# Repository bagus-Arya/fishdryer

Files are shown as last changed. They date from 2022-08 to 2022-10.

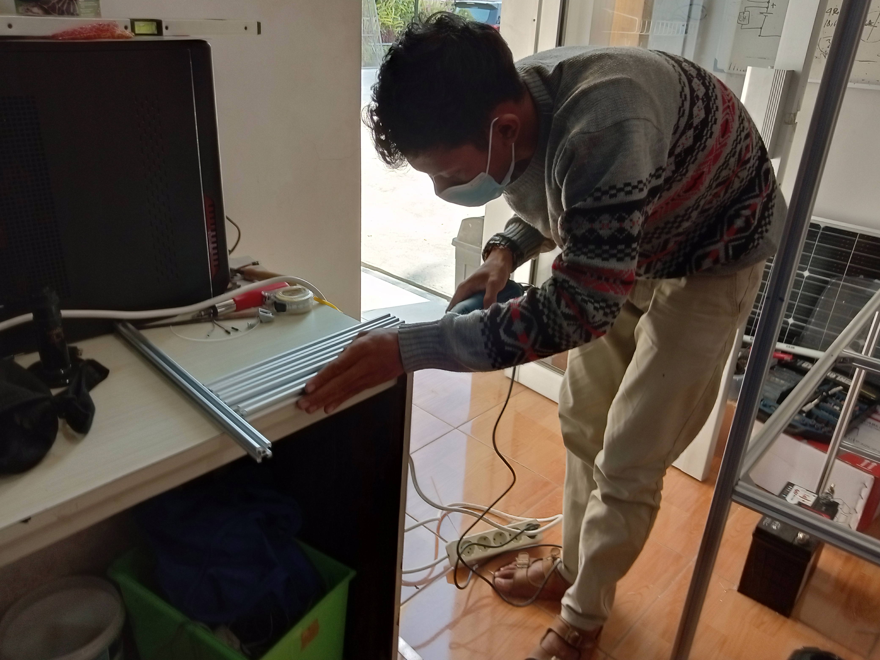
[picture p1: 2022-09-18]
Laporan kemajuan fisheris/foto/IMG_20220820_165149_140.jpg

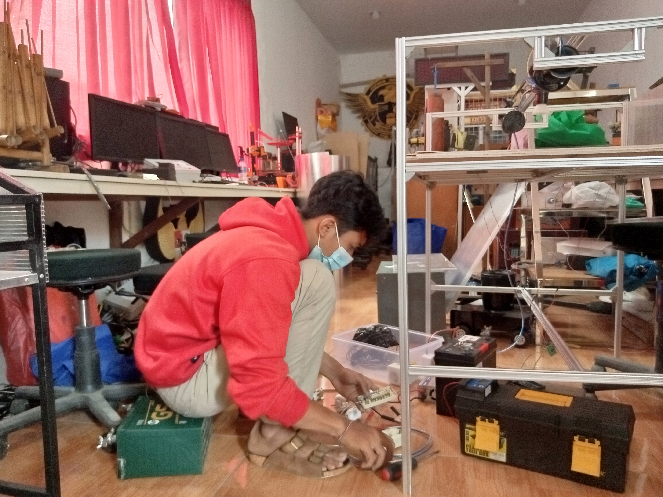
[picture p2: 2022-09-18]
Laporan kemajuan fisheris/foto/IMG_20220829_140725_547.jpg

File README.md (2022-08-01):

<p align="center"></p>

<p align="center">




</p>

## About Laravel

Laravel is a web application framework with expressive, elegant syntax. We believe development must be an enjoyable and creative experience to be truly fulfilling. Laravel takes the pain out of development by easing common tasks used in many web projects, such as:

- [Simple, fast routing engine](https://laravel.com/docs/routing).
- [Powerful dependency injection container](https://laravel.com/docs/container).
- Multiple back-ends for [session](https://laravel.com/docs/session) and [cache](https://laravel.com/docs/cache) storage.
- Expressive, intuitive [database ORM](https://laravel.com/docs/eloquent).
- Database agnostic [schema migrations](https://laravel.com/docs/migrations).
- [Robust background job processing](https://laravel.com/docs/queues).
- [Real-time event broadcasting](https://laravel.com/docs/broadcasting).

Laravel is accessible, powerful, and provides tools required for large, robust applications.

## Learning Laravel

Laravel has the most extensive and thorough [documentation](https://laravel.com/docs) and video tutorial library of all modern web application frameworks, making it a breeze to get started with the framework.

If you don't feel like reading, [Laracasts](https://laracasts.com) can help. Laracasts contains over 2000 video tutorials on a range of topics including Laravel, modern PHP, unit testing, and JavaScript. Boost your skills by digging into our comprehensive video library.

## Laravel Sponsors

We would like to extend our thanks to the following sponsors for funding Laravel development. If you are interested in becoming a sponsor, please visit the Laravel [Patreon page](https://patreon.com/taylorotwell).

### Premium Partners

- **[Vehikl](https://vehikl.com/)**
- **[Tighten Co.](https://tighten.co)**
- **[Kirschbaum Development Group](https://kirschbaumdevelopment.com)**
- **[64 Robots](https://64robots.com)**
- **[Cubet Techno Labs](https://cubettech.com)**
- **[Cyber-Duck](https://cyber-duck.co.uk)**
- **[Many](https://www.many.co.uk)**
- **[Webdock, Fast VPS Hosting](https://www.webdock.io/en)**
- **[DevSquad](https://devsquad.com)**
- **[Curotec](https://www.curotec.com/services/technologies/laravel/)**
- **[OP.GG](https://op.gg)**
- **[WebReinvent](https://webreinvent.com/?utm_source=laravel&utm_medium=github&utm_campaign=patreon-sponsors)**
- **[Lendio](https://lendio.com)**

## Contributing

Thank you for considering contributing to the Laravel framework! The contribution guide can be found in the [Laravel documentation](https://laravel.com/docs/contributions).

## Code of Conduct

In order to ensure that the Laravel community is welcoming to all, please review and abide by the [Code of Conduct](https://laravel.com/docs/contributions#code-of-conduct).

## Security Vulnerabilities

If you discover a security vulnerability within Laravel, please send an e-mail to Taylor Otwell via [taylor@laravel.com](mailto:taylor@laravel.com). All security vulnerabilities will be promptly addressed.

## License

The Laravel framework is open-sourced software licensed under the [MIT license](https://opensource.org/licenses/MIT).
# fishdryer

# fishdryer

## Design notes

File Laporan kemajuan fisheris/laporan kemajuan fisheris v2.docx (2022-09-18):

Pengisian poin C sampai dengan poin H mengikuti template berikut dan tidak dibatasi jumlah kata atau halaman namun disarankan seringkas mungkin. Dilarang menghapus/memodifikasi template ataupun menghapus penjelasan di setiap poin.

C. HASIL PELAKSANAAN PENELITIAN: Tuliskan secara ringkas hasil pelaksanaan penelitian yang telah dicapai sesuai tahun pelaksanaan penelitian. Penyajian meliputi data, hasil analisis, dan capaian luaran (wajib dan atau tambahan). Seluruh hasil atau capaian yang dilaporkan harus berkaitan dengan tahapan pelaksanaan penelitian sebagaimana direncanakan pada proposal. Penyajian data dapat berupa gambar, tabel, grafik, dan sejenisnya, serta analisis didukung dengan sumber pustaka primer yang relevan dan terkini.

I. Perancangan Sistem

Dalam membangun sistem pengeringan ikan ini,tahap pertama yang dilakukan adalah proses perancangan.Pada tahap ini peneliti akan menganalisa kebutuhan sistem dan mendesign sistem baik dari segi sofware ataupun hardwarenya.

  A. Analisi Kebutuhan Sistem

Analisis kebutuhan sistem dilakukan untuk mengindentifikasi fungsi utama yang tersedia pada sistem yang dibangun.Berikut merupakan analisi kebutuhan sistem pada penelitian ini.

1) Sistem dapat melindungi kondisi fisik ikan dari serangga,belatung ataupun cuaca yang tidak mendukung.
2) Sistem dapat memberikan penghangat saat kondisi cuaca kurang baik atau pada malam hari.
3) Sistem mampu memantau suhu ,berat dan intensitas cahaya di sekitarnya.
4) Sistem mampu mengirimkan data-data suhu, berat dan intentsitas cahaya ke website dan menampilkan data tersebut dalam bentuk graph untuk memudahkan nelayan memantau kondisi ikan dan lingkuan sekitar area pengeringan.
5) Sistem akan menggunakan solar panel dan aki sebagai power supply sistem.
  B. Blok Diagram

Gambar 3. Blok Diagram Sistem

Diagram blok dari sistem pegeringan ikan dapat dilihat pada Gambar 3. blok diagram sistem.Arduino mega dan sim module 900 mendapatkan daya dari batrai aki 12v/5Ah yang telah di turunkan teganganya dari 12v dc menjadi 5v dc menggunakan buck converter. Pengecasan aki dilakukan secara otomatis menggunakan charge controller yang telah terhubung dengan panel surya.Batrai aki 12v langsung terhubug ke relay untuk memberikan tegangan ke inverter, sehingga lampu dan heater bertengangan220v dapat menyala. Relay dikontrol oleh microcontroller yang mendapatkan inputan nilai lux meter module. Terdapat 3 inputan yaitu sensor suhu menggunakan ds18b20, sensor berat loadcell 50kg, dan Lux meter module menggunakan bh1750. Arduino mega mengolah data inputan kemudian sim module 900 mengirimkan data tersebut ke website, dan pengguna dapat melihat informasi berat,suhu,dan intensitas cahaya dari website dengan tampilan graph data. Data suhu dan berat juga dapat dilihat langsung melalui LCD Module.

  C. Flow Chart

Gambar 4. Flowchart Sistem

Flow kerja sistem dapat dilihat pada Gambar 4. Flowchart Sistem.Pertama-tama Arduino akan melakukan inisialisasi dan penyetingan awal sensor-sensor dan module sim guna mengecek kesiapan module-module tersebut.Setelah semua komponen sudah berjalan dengan baik, Arduino mega akan mengambil data suhu,berat,intensitas cahay serta sinyal gsm dari module-module yang sudah terinisialisasi sebelumnya.Lalu arduino mega akan menampilkan data-data tersebut ke LCD untuk memperlihatkan status kondisi lingkungan sekitar sistem.Lalu sistem akan mengecek apakah data intesitas cahaya yang di dapatkan kurang dari 150 lx.Jika iya maka arduino akan menghidupkan lampu dan heater dari sistem pengeringan ikan.Jika tidak maka lampu dan heater akan mati.Setelah itu arduino mega akan mengirimkan data-data yang didapatkan dari proses sebelumnya ke website menggunakan sim module setiap 30 detik.Jika waktu pengiriman data sudah sama atau lebih dari 30 detik maka data akan dikirim ke website. Jika tidak maka arduino mega akan kembali ke proses pengambilan data-data sensor dan sinyal gsm.

  D. Skematik Alat

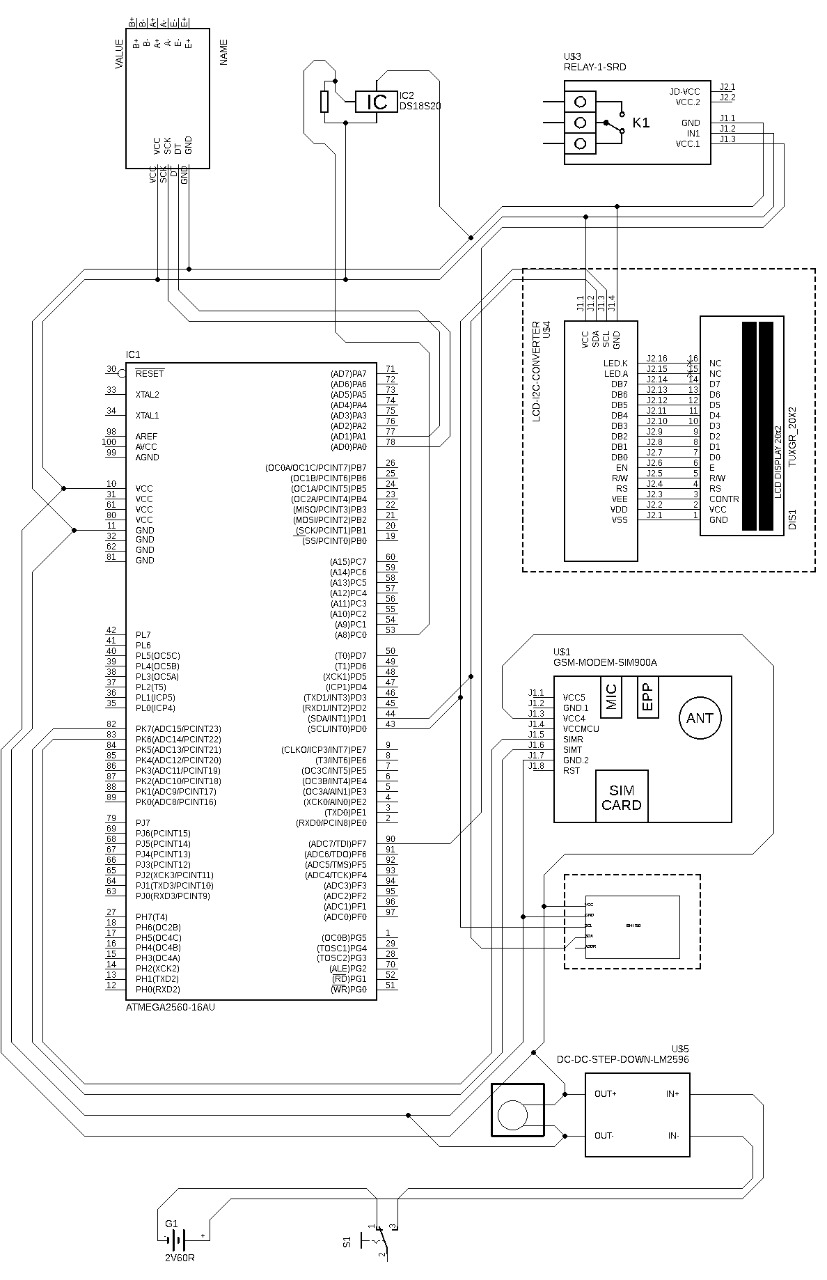
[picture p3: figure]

Gambar 5. Skematik Sistem

Skematik rangkaian dari alat pengeringan ikan ditunjukkan pada Gambar 5. Terdapat 1 buck converter yang terhubung dengan microcontroller Atmega2560 dan modul GSM SIM 900.SIM 900 akan terhubung ke pin rx dan tx pada microcontroller untuk berkomonukasi secara serial.Sedangkan LCD dan sensor lux BH1750 akan terkoneksi ke pin sda dan scl microcontroller untuk berkomunikasi dengan protokol I2C.Sensor DS18B20 akan terkonesi ke pin PC0 yang dimana pin tersebut memiliki kemampuan untuk membaca analog input.Relay akan terkonesi ke pin PF7 yang akan memberikan sinyal relay untuk menghidup matikan lampu.Dan yang terakhir adalah HX1711 yang dimana pin DT dan SCK akan terhubung ke pin PA1 dan PA0.

  E. Peracangan Design PCB

Berdasarkan dari skematik yang telah dirancang maka dibuatlah Peracngan PCB sebagai berikut Pada Gambar dibawah ini

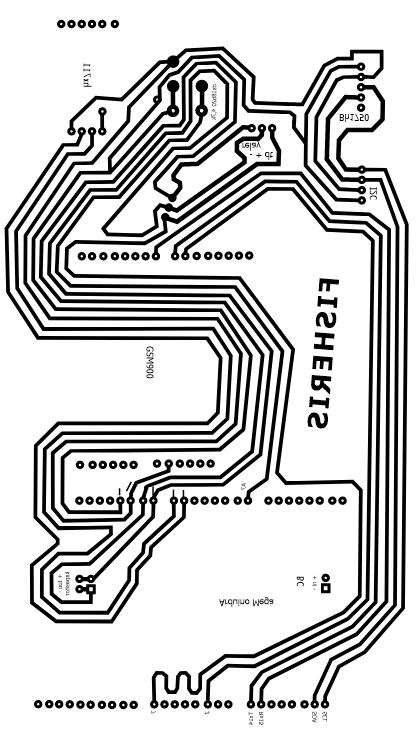
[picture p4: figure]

Gambar 6. Design PCB

  F. Perancangan Box Kontroller Solar Panel,Tempat Pengeringan Ikan dan Penyangga Solar Panel

Pada sisi hardware terdapat 2 bagian utama dari sistem yaitu perancangan box kontroller dan tempat pengeringan ikan.

1) Box Kontroller

Box kontroller adalah tempat menaruh komponen-komponen elektrikal yang di butuhkan untuk menjalankan sistem.Box ini akan melindungi komponen-komponen electrikal dari pengaruh korosif kondisi pantai yang membuat bahan metal berkarat.Box ini berukuran x x x . Pada Gambar 7. Merupakan gambar box kontroller dari sistem yang di buat.

Gambar 7. Box Kontroller

2) Tempat Pengeringan Ikan

Tempat pengeringan ikan merupakan tempat diamana proses pengeringan ikan akan dilakukan.Tempat pengeringan ikan ini dibuat menggunakan aluminium profile dengan dimensi x x x.Di tempat pengeringan ikan ini akan ditaruh 1 lampu dan 2 buah heater dan sistem timbangan untuk mengukur berat ikan.

Gambar 8. Tempat Pengeringan Ikan

  G. Peracangan Tampilan Website
    1) Tampilan Halaman Login

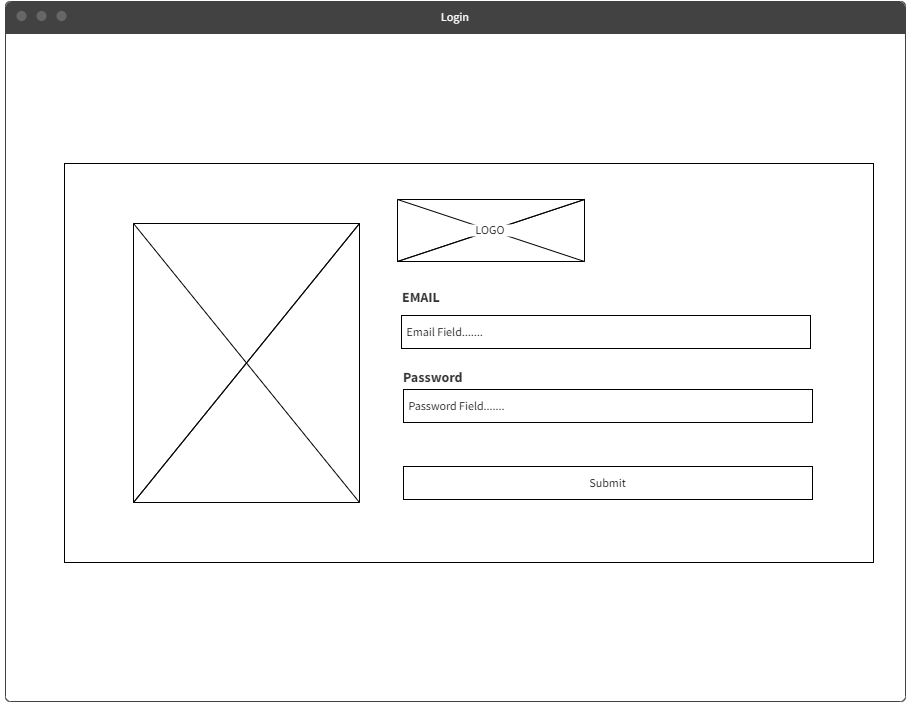
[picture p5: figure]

Gambar 8. Tampilan Halaman Login

Halaman login merupakan halaman yang pertama kali muncul saat mengakses website.Untuk dapat melihat data-data yang telah dikirimkan oleh sistem pengering ikan.User harus terlebih dahulu melakukan login ke website dengan menggunakan email dan password yang sudah terdaftar.

    2) Tampilan Halaman Dashboard

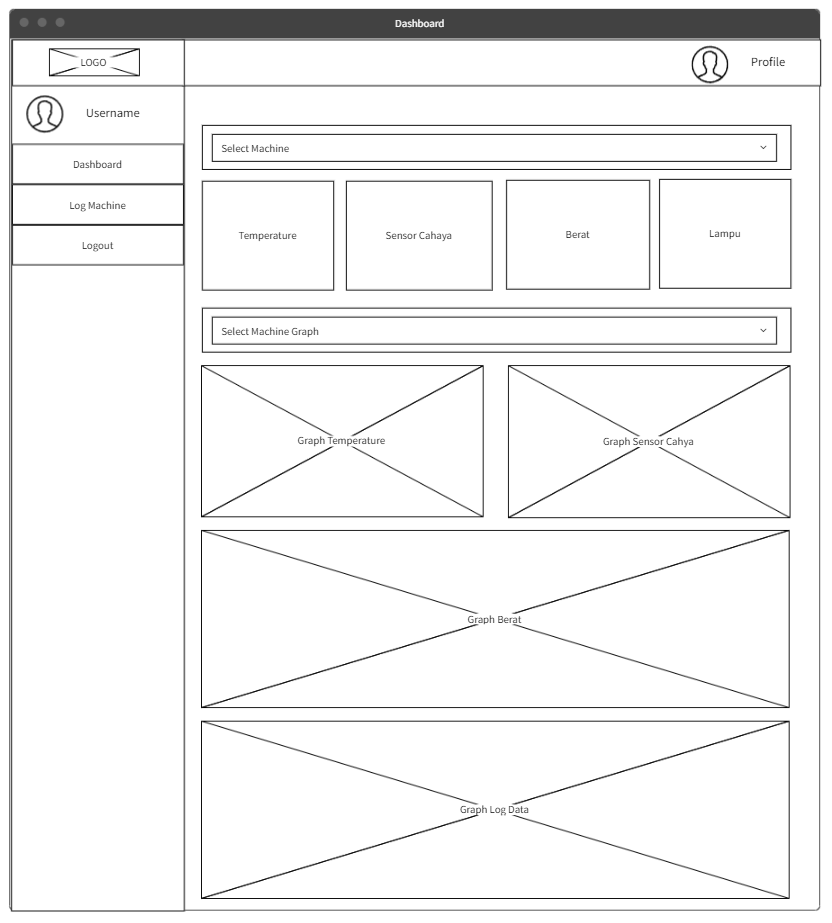
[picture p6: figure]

Gambar 9. Tampilan Halaman Dashboard

Jika login berhasil maka webrowser akan mengarahkan user ke halaman dashboard.Pada halaman ini akan terdapat data yang telah di filter dan diolah dalam bentuk graph chart dan line char.Selain itu terdapat juga tampilan data terakhir yang dikirimkan oleh sistem pengeringan ikan.

    3) Tampilan Halaman Log Machine

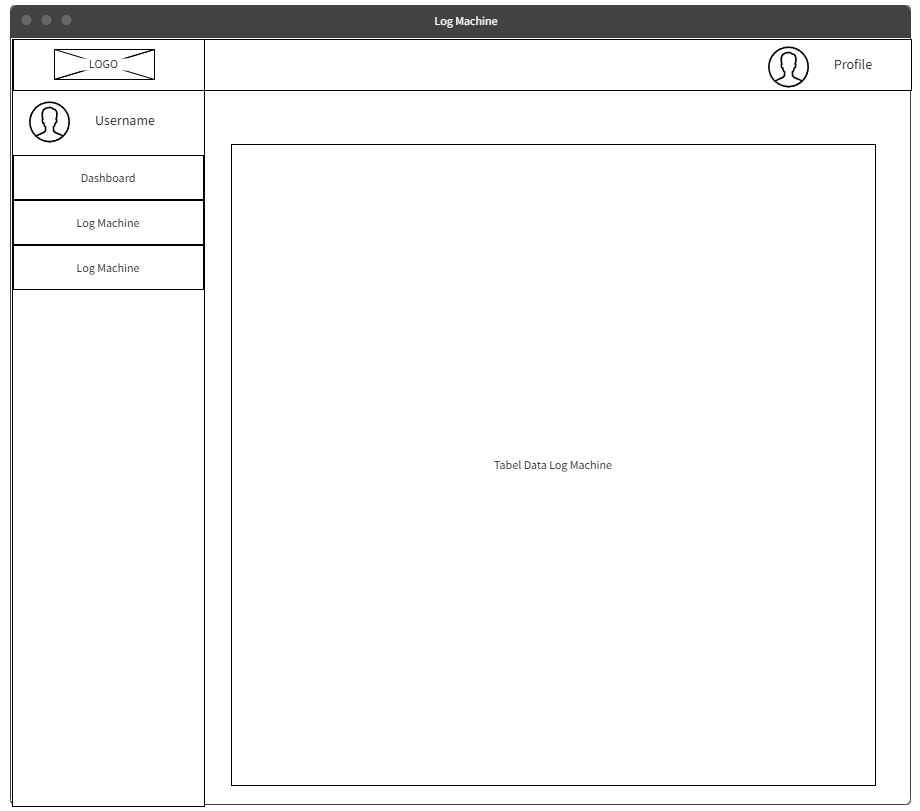
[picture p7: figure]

Gambar 10. Tampilan Halaman Dashboard Line Chart

Tampilan Halaman Log Machine merupakan tampilan history data-data yang dikirimkan oleh sistem pengeringan ikan dalam bentuk tabel.

II. Implementasi Sistem

D. STATUS LUARAN: Tuliskan jenis, identitas dan status ketercapaian setiap luaran wajib dan luaran tambahan (jika ada) yang dijanjikan. Jenis luaran dapat berupa publikasi, perolehan kekayaan intelektual, hasil pengujian atau luaran lainnya yang telah dijanjikan pada proposal. Uraian status luaran harus didukung dengan bukti kemajuan ketercapaian luaran sesuai dengan luaran yang dijanjikan. Lengkapi isian jenis luaran yang dijanjikan serta mengunggah bukti dokumen ketercapaian luaran wajib dan luaran tambahan melalui Simlitabmas.

………………………………………………………………………………………………………………………………………………………………………………………………………………………………………………………………………………………………………………………………………………………………………………………………………………………………………………………………………………………………………………………………………………………………………………………………………………………

E. PERAN MITRA: Tuliskan realisasi kerjasama dan kontribusi Mitra baik in-kind maupun in-cash (untuk Penelitian Terapan, Penelitian Pengembangan, PTUPT, PPUPT serta KRUPT). Bukti pendukung realisasi kerjasama dan realisasi kontribusi mitra dilaporkan sesuai dengan kondisi yang sebenarnya. Bukti dokumen realisasi kerjasama dengan Mitra diunggah melalui Simlitabmas.

………………………………………………………………………………………………………………………………………………………………………………………………………………………………………………………………………………………………………………………………………………………………………………………………………………………………………………………………………………………………………………………………………………………………………………………………………………………

F. KENDALA PELAKSANAAN PENELITIAN: Tuliskan kesulitan atau hambatan yang dihadapi selama melakukan penelitian dan mencapai luaran yang dijanjikan, termasuk penjelasan jika pelaksanaan penelitian dan luaran penelitian tidak sesuai dengan yang direncanakan atau dijanjikan.

Kesulitan dan hambatan yang dihadapi dalam melakukan penelitian dan mencapai luaran adalah terlambatnya penerimaan dana hibah penelitian dan pemberlakuan PPKM di Bali yang membuat proses pengembangan dan prototyping sistem juga terlambat.

G. RENCANA TAHAPAN SELANJUTNYA: Tuliskan dan uraikan rencana penelitian di tahun berikutnya berdasarkan indikator luaran yang telah dicapai, rencana realisasi luaran wajib yang dijanjikan dan tambahan (jika ada) di tahun berikutnya serta roadmap penelitian keseluruhan. Pada bagian ini diperbolehkan untuk melengkapi penjelasan dari setiap tahapan dalam metoda yang akan direncanakan termasuk jadwal berkaitan dengan strategi untuk mencapai luaran seperti yang telah dijanjikan dalam proposal. Jika diperlukan, penjelasan dapat juga dilengkapi dengan gambar, tabel, diagram, serta pustaka yang relevan. Jika laporan kemajuan merupakan laporan pelaksanaan tahun terakhir, pada bagian ini dapat dituliskan rencana penyelesaian target yang belum tercapai.

Penelitian ini masih dalam tahap pelaksanaan. Rencana kegiatan yang akan dilakukan pada tahapan berikutnya

adalah sebagai berikut:

1. Melakukan uji coba tahap pertama untuk prototype sistem yang telah dibangun,
2. Jika alat sudah bekerja sesuai harapan dari peneliti maka sistem akan langsung di terapkan di tempat
3. Mengabil data dan feedback berdasarkan sistem yang di implementasikan
4. Evaluasi kebutuhan sistem untuk rencana pengembangan tahun ke-2.

………………………………………………………………………………………………………………………………………………………………………………………………………………………………………………………………………………………………………………………………………………………………………………………………………………………………………………………………………………………………………………………………………………………………………………………………………………………

H. DAFTAR PUSTAKA: Penyusunan Daftar Pustaka berdasarkan sistem nomor sesuai dengan urutan pengutipan. Hanya pustaka yang disitasi pada laporan kemajuan yang dicantumkan dalam Daftar Pustaka.

1. …………………………………………………………………………………………………………………
2. …………………………………………………………………………………………………………………
3. dst.

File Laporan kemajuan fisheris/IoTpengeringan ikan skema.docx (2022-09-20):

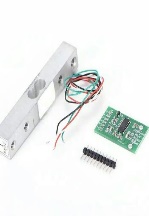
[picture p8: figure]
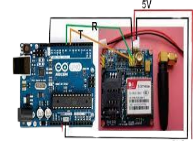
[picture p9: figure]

Data disimpan pada cloud server menggunakan API

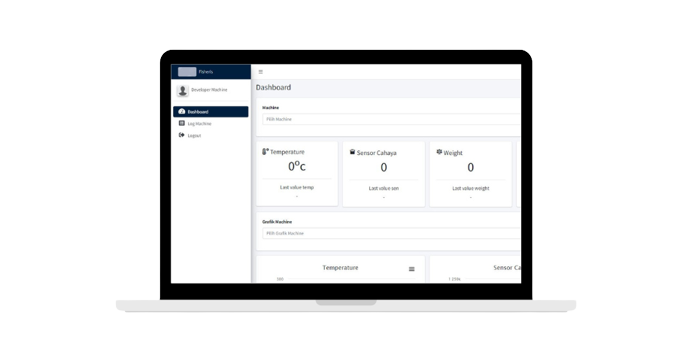
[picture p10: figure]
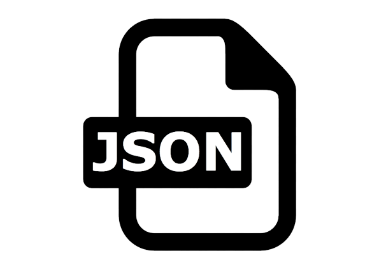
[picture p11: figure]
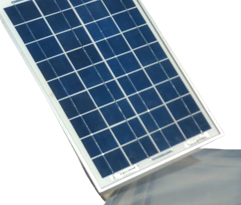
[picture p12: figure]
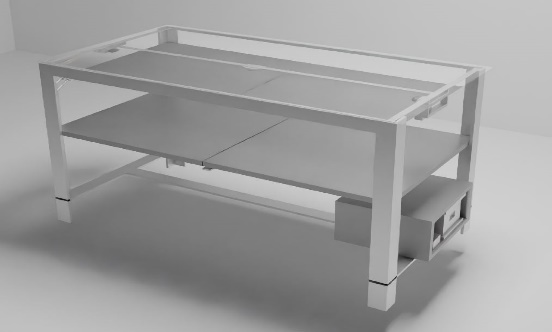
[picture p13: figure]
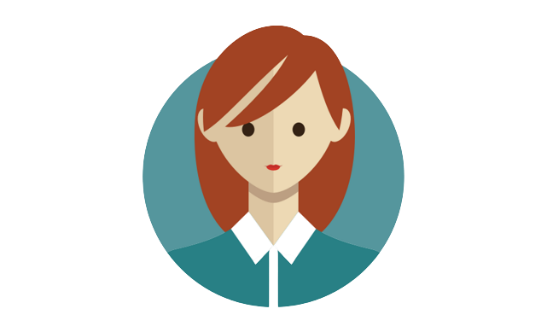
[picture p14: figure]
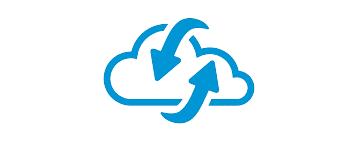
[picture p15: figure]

Tampilan data monitoring

Data Json diolah menggunakan bahasa PHP

User (Pelaku Pengeringan Ikan)

Sistem Pengeringan Ikan

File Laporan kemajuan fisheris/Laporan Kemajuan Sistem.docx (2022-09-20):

Laporan Kemajuan

## Pengumpulan Data

Pada tahap ini dilakukan proses pengumpulan data untuk pengembangan sistem informasi yang dapat digunakan untuk melakukan monitoring proses pengeringan ikan. Setelah dikembangkan alat pengering ikan menggunakan teknologi IOT selanjutnya data akan dikirimkan ke cloud. Data yang dihasilkan pada alat pengering ikan berupa suhu, berat dan intensitas cahaya. Sistem pada alat pengering ikan akan mengirimkan data secara berkala dalam selang waktu tertentu ke server. Pengguna dapat melakukan pemantauan pada website dengan menggunakan laptop atau handphone. Pengguna nantinya akan diberikan akses untuk memantau proses pengeringan ikan. Dengan adanya sistem informasi diharapkan proses pengeringan dapat berjalan secara baik. Sistem akan menampilkan rangkuman informasi proses pengeringan yang sedang berjalan. Untuk menentukan proses tersebut dikembangkan sebuah basis pengetahuan berdasarkan data yang terkirim ke server.

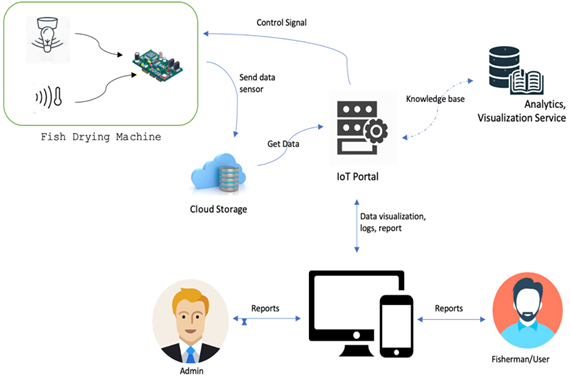
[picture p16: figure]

Gambar 1. Fish Dryer Machine Information System Architecture

## Analisis Sistem

Unified modelling language (UML) digunakan untuk pemodelan sistem yang dibangun. Dengan digunakannya UML diharapkan dapat memberikan suatu gambaran model atau sebagai bahasa pemodelan visual yang ekspresif dalam pengembangan sistem dan mempermudah pengguna untuk membaca sistem yang akan dibangun. Pada penelitian ini akan digunakan diagram use case, activity diagram, sequence diagram dan class diagram.

Gambar 2 menjelaskan use case diagram, dimana terdapat 8 use case atau proses yang dapat dilakukan. Use case diagram menggambarkan bagaimana interaksi yang terjadi antara aktor dengan sistem. Ada 3 level user yang terlibat yaitu admin, nelayan dan alat pengering ikan. Admin dapat mengelola data master, melihat riwayat data masuk, laporan dan dashboard. Nelayan dapat melihat dashboard dan menginputkan hasil tangkapan. Alat pengering ikan dapat mengirimkan data dari pembacaan sensor dan proses sinyal kontrol.

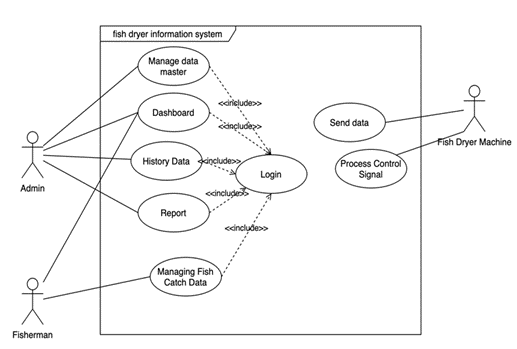
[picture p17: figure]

Gambar 2. Use Case Diagram Fish Dryer Information System

Gambar 3 menjelaskan activity diagram untuk menu dashboard. Menu dashboard menampilkan informasi dari alat pengering seperti status alat, energy, kondisi terakhir untuk suhu, berat dan cahaya, serta riwayat pengiriman data.

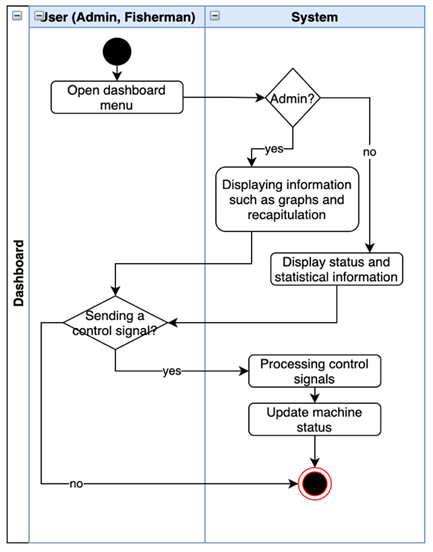
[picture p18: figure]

Gambar 3. Activity Diagram for Dashboard

Gambar 4 menjelaskan sequence diagram untuk proses input hasil tangkapan dari nelayan. Proses tersebut dapat digunakan untuk mendata tangkapan ikan nelayan per harinya.

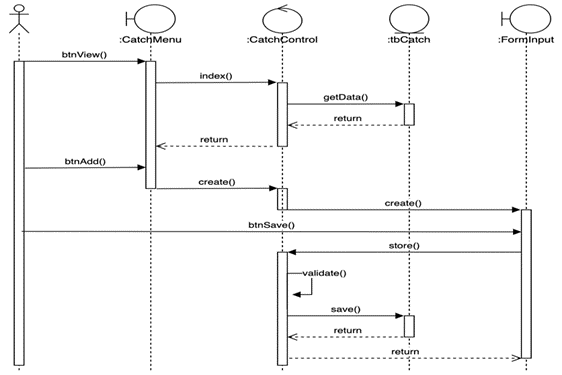
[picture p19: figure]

Gambar 4. Sequence Diagram to Input Fish Catch

Gambar 5 menjelaskan class diagram untuk sistem yang akan dibangun. Analisis pembentukan class diagram merupakan aktivitas inti yang sangat mempengaruhi arsitektur sistem yang dirancang hingga ke tahap pengkodean.

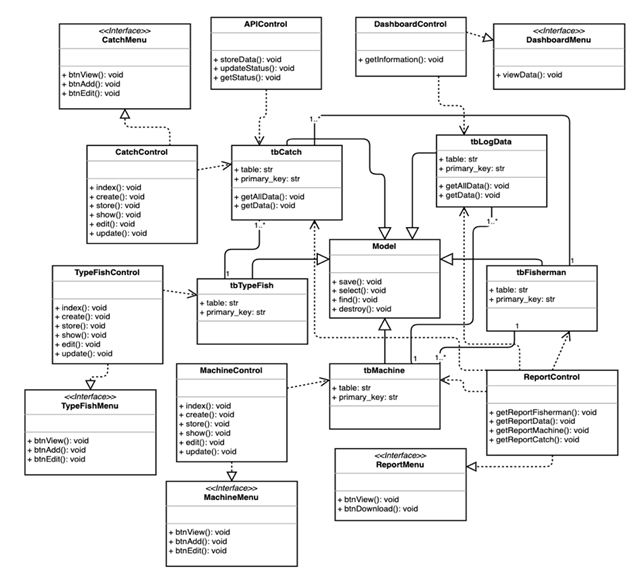
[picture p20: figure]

Gambar 5. Class Diagram Fish Dryer Information System

## Komunikasi data

Komunikasi antara mesin pengering ikan dan sistem informasi yang dibangun menggunakan web Application Programming Interface (API). Melalui web API mesin pengering dapat melakukan proses insert yang bekerja melalui HTTP dengan method POST. Format data yang digunakan yaitu menggunakan JavaScript Object Notation (JSON). Berikut list API yang akan digunakan dalam pengembangan sistem.

Tabel 1. List API
Method | | Parameter | Data Type
InsertData | Request | id | String
| | temperature | Decimal
| | weight | Decimal
| | lux | Decimal
| | relay | Boolean
| | lat | Decimal
| | long | Decimal
| Response | status | String
| | message | String
| | data | Array
| | id | String
| | created_date | Datetime

Implementasi

Sebelum implementasi, hasil prototype dari sistem baru dilakukan evaluasi dengan pengguna terlebih dahulu. Tahap tersebut untuk memastikan apakah rancangan prototype sudah sesuai dengan kebutuhan pengguna. Jika masih belum sesuai, pengembang perlu melakukan penyesuaian kembali. Jika sudah disetujui maka tahap implementasi dapat dilakukan. Pengembang sistem membangun sistem berdasarkan rancangan yang telah disetujui.

Pembangun sistem menggunakan framework laravel dan bahasa pemrograman PHP. Untuk skema data menggunakan class entity yang terdapat pada class diagram. Database yang digunakan adalah MongoDB. MongoDB mempunyai kelebihan pada data tidak terstruktur dan tidak perlu menentukan skema. Komunikasi antara mesin pengering ikan dan sistem yang dibangun bisa bersifat dinamis menyesuaikan dengan kebutuhan informasi. Gambar 6 merupakan tampilan awal login untuk masuk ke dalam sistem informasi alat pengering ikan (Fisheris).

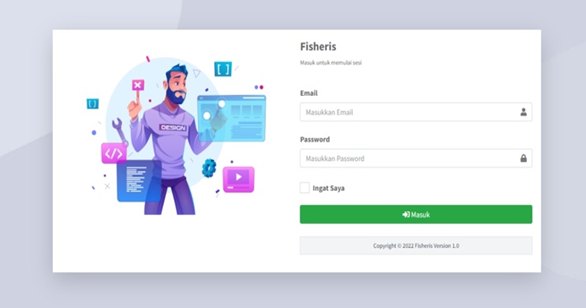
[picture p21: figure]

Gambar 6. Implementation of Login

Gambar 7 adalah tampilan menu dashboard. Admin atau nelayan dapat mengakses menu ini untuk melakukan pemantauan proses pengeringan.

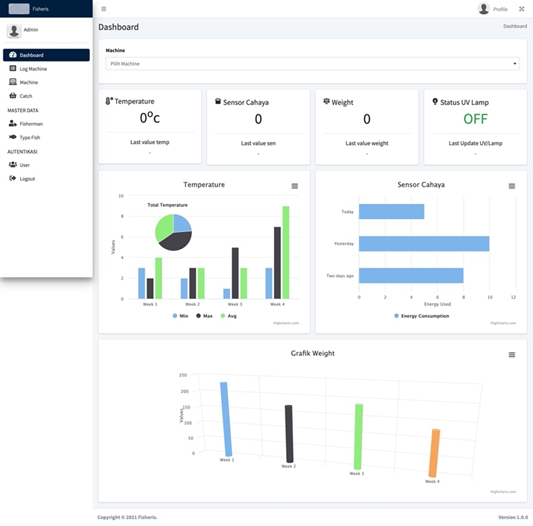
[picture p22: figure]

Gambar 7. Implementation of User Interface for Dashboard Menu

Gambar 8 adalah tampilan untuk melakukan pengelolaan data nelayan yang terdaftar ke dalam sistem. Proses ini dapat dilakukan oleh admin. Nelayan harus terdaftar untuk mendapatkan user login.

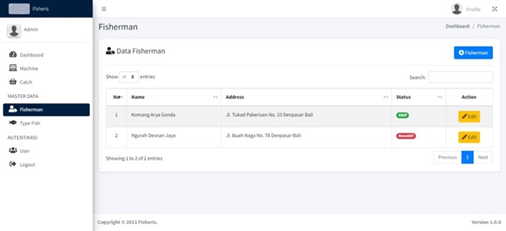
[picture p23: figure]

Gambar 8. Implementation of Manage Fisherman

## Pengujian

Pengujian dalam penelitian ini menggunakan metode black box testing. Tujuan dilakukan pengujian adalah memastikan fungsionalitas dari menu yang sudah diimplementasikan dapat berjalan sesuai dengan yang diharapkan. Beberapa skenario pengujian telah dirancang dengan mengkondisikan beberapa input yang akan dimasukkan ke dalam sistem dan dilakukan pengamatan terhadap hasil yang dikeluarkan. Jika masih terjadi kesalahan maka diperlukan kembali tahap revisi sampai sistem berjalan dengan baik.

Tabel 1. Black box testing
Input | Proses | Output | Result
Username and password | Log in to system | View dashboard pages | | Succeed
Select machine in dashboard menu | Displaying machine information | Displays summary of machine information as a whole
Click log machine menu | Displaying log data | Viewing data that has been entered from the machine | | Succeed
Click machine menu | Displaying machine page | - Add machine - Edit machine data | | Succeed
Click fisherman menu | Displaying fisherman page | - Add fisherman - Edit fisherman data | | Succeed
Click user menu | Displaying user page | - Add user - Edit user data | | Succeed
Click type fish menu | Displaying type fish page | - Add type fish - Edit type fish data | | Succeed
Click logout | Clear login cache | Out of the system | | Succeed
Access the dashboard menu via url before login | Check session login | Redirected to login page | | Succeed

Perhitungan Solar Cell

Alat pengeringan ikan ini menggunakan sumber energi dari panel surya sebesar 100 WP dan penyimpanan batrai 12v 65 Ah, kemudian tegangan akan diturunkan menjadi 4,9 VDC menggunakan Buck Converter. Sistem PV ini mampu memenuhi 169.95% dari 240 Wh/hari energi listrik dari pengeringan. Beban listrik terdapat 10W UV lamp dan 5W sistem kontrol. Sistem kelistrikan pada alat pengeringan ikan dapat dilihat dari Gambar 2.

This fish dryer uses an electrical energy source from a 100 WP solar panel and a 12 V 65 Ah storage battery, which is then lowered to 4.9 VDC using a buck converter. This PV system can meet 169.95% of the need for 240 Wh/day of electrical energy from the dryer. The electrical load of this system comes from a 10W UV lamp and a 5W control system. The electrical system of the fish drying device can be seen in Figure 2.

Figure 2. The electrical system of the fish drying device

Selama pemanfaatan alat pengeringan ikan di desa Seraya, PV dapat menghasilkan energi listrik sebesar 407,81 Wh/hari, energi terbesar dapat mencapai 520 Wh dan terkecil 160,8 Wh. Perbedaan energi keluaran yang dihasilkan disebabkan oleh beberapa faktor lingkungan, diantaranya suhu udara, kecepatan angin, dan kelembaban udara di sekitar lokasi pemasangan alat pengering ikan. Kondisi lingkungan selama 31 hari dapat dilihat pada Tabel 1, sedangkan energi keluaran dari PV yang dipasang pada alat pengering ikan dapat dilihat pada Gambar 3.

During the utilization of fish dryers in Seraya Village, PV can produce electrical energy of 407.81 Wh/day, where the largest energy can reach 520 Wh and the smallest is 160.8 Wh. The difference in output energy produced is caused by several environmental factors, including air temperature, wind speed, and air humidity around the installation location of the fish dryer. The environmental conditions for 31 days can be seen in Table 1, while the energy output from PV installed on the fish dryer can be seen in Figure 3.

Table 1. The environmental conditions at Seraya Village

Day | Temperature (oC) | Wind Speed (m/s) | Humidity (%)
1 | 27.71 | 2.62 | 79.25
2 | 27.84 | 2.17 | 81.12
3 | 27.64 | 1.71 | 81.06
4 | 27.57 | 1.37 | 80.5
5 | 27.45 | 1.4 | 82.75
6 | 27.01 | 2.53 | 85.12
7 | 26.23 | 1.19 | 80.94
8 | 27.08 | 1.82 | 80.44
9 | 27.37 | 2.02 | 81.62
10 | 27.24 | 2.56 | 85.19
11 | 27.41 | 3.03 | 84.56
12 | 27.8 | 3.48 | 78.69
13 | 28 | 1.53 | 72.75
14 | 28.12 | 1.84 | 72.25
15 | 28.24 | 1.55 | 73.88
16 | 27.7 | 2.7 | 83.5
17 | 27.79 | 2.8 | 81.81
18 | 27.83 | 2.23 | 79.5
19 | 27.9 | 3.12 | 82.31
20 | 27.64 | 3.49 | 83.75
21 | 27.3 | 3.74 | 85
22 | 27.33 | 3.62 | 84.44
23 | 27.23 | 3.46 | 85.19
24 | 27.99 | 2.8 | 83.19
25 | 28.11 | 2.13 | 83.38
26 | 27.83 | 2.68 | 85.75
27 | 27.57 | 3.8 | 82.69
28 | 27.51 | 2.48 | 81
29 | 27.8 | 1.69 | 82.56
30 | 27.42 | 2.3 | 85.94
31 | 27.77 | 1.77 | 79.31

Figure 2. Energy output from PV installed on the fish dryer

3.2. Socio-economic testing of the use of fish dryer

Pada Tabel 2 dapat dilihat hasil uji-t berpasangan terhadap dampak sosial penggunaan alat pengering ikan pada nelayan. Nilai signifikansi sebesar 0,000 (p < 0,05), artinya terdapat perbedaan yang signifikan antara rata-rata dampak sosial penggunaan alat pengering ikan sebelum dan sesudah penggunaan. Jika dampak sosial penggunaan alat pengering ikan tidak berbeda antara sebelum dan sesudah penggunaan, maka faktor probabilitas dapat menjelaskan 0,00% sehingga diperoleh perbedaan rata-rata sebesar 5,37. Karena peluang untuk menjelaskan hasil yang diperoleh < 5%, maka hasil tersebut signifikan. Hasil penelitian juga menunjukkan bahwa dari hasil analisis diperoleh kepercayaan 95%, dimana jika dilakukan pengukuran terhadap populasi, maka perbedaan dampak sosial sebelum dan sesudah penggunaan alat pengering ikan adalah antara 4,820 - 5,921. Variabel-variabel yang dibahas dalam dampak sosial ini adalah keamanan, kebersihan, dan pemanfaatan lahan pengering ikan.

Pada Tabel 3 terlihat bahwa hasil uji-t berpasangan telah menunjukkan dampak ekonomi penggunaan alat pengering ikan terhadap nelayan. Nilai signifikansi sebesar 0,000 (p < 0,05), artinya terdapat perbedaan yang signifikan antara rata-rata dampak ekonomi penggunaan alat pengering ikan sebelum dan sesudah penggunaan. Jika dampak ekonomi penggunaan alat pengering ikan tidak berbeda antara sebelum dan sesudah penggunaan, maka faktor probabilitas dapat menjelaskan sebesar 0,00% sehingga diperoleh perbedaan rata-rata sebesar 7,96. Karena peluang untuk menjelaskan hasil yang diperoleh < 5%, maka hasil tersebut signifikan. Hasil penelitian juga menunjukkan bahwa dari hasil analisis diperoleh kepercayaan 95%, dimana jika dilakukan pengukuran terhadap populasi, maka perbedaan dampak sosial sebelum dan sesudah penggunaan alat pengering ikan adalah antara 6,99 - 8,94. Variabel yang dibahas dalam dampak ekonomi ini adalah tambahan pendapatan yang diperoleh nelayan, efisiensi, biaya operasional, dan kesempatan kerja.

In the Table 2, it can be seen the results of the paired t-test on the social impact of using fish dryers on fishermen. The significance value was 0.000 (p < 0.05), meaning that there was a significant difference between the average social impact of using fish dryers before and after use. If the social impact of using a fish dryer does not differ between before and after use, then the probability factor can explain 0.00% to obtain an average difference of 5.37. Because the opportunity to explain the results obtained is < 5%, then these results are significant. The results also show that from the results of the analysis, 95% confidence is obtained, where if measurements are made on the population, the difference in social impacts before and after the use of fish dryers is between 4,820 – 5,921. The variables discussed in this social impact are safety, cleanliness, and land use of the fish dryer.

In the Table 3, it can be seen that the results of the paired t-test have shown the economic impact of using fish dryers on fishermen. The significance value was 0.000 (p < 0.05), meaning that there was a significant difference between the average economic impact of using fish dryers before and after use. If the economic impact of using a fish dryer does not differ between before and after use, then the probability factor can explain 0.00% to obtain an average difference of 7.96. Because the opportunity to explain the results obtained is < 5%, then these results are significant. The results also show that from the analysis, 95% confidence is obtained, where if measurements are made on the population, the difference in social impacts before and after the use of fish dryers is between 6.99 – 8.94. The variables discussed in this economic impact are additional income earned by fishermen, efficiency, operational costs, and employment opportunities.

Table 2. Paired T test results social impact of using fish dryer

| n | Mean±s.d | Mean Difference±s.d | 95% Confidence Interval | P
Social impact before using fish dryer | 27 | 10.07±1.07 | 5.37±1.40 | 4.82 – 5.92 | < 0.005
Social impact after using fish dryer | 27 | 15.44±1.31

Table 3. Paired T test results economic impact of using fish dryer

| n | Mean±s.d | Mean Difference±s.d | 95% Confidence Interval | p
Economic impact before using fish dryer | 27 | 11.11±1.72 | 7.96±2.46 | 6.99 – 8.94 | < 0.005
Economic impact after using fish dryer | 27 | 19.07±1.54

Hasil penggunaan alat pengering ikan oleh nelayan juga dianalisis dengan distribusi frekuensi. Hasil tersebut diperoleh berdasarkan beberapa kriteria, seperti persepsi nelayan terhadap alat, kesesuaian penggunaan alat, faktor manfaat, dan bentuk alat pengering ikan. Jika dilihat dari persepsi nelayan terhadap alat tersebut memberikan nilai rata-rata 4,67 yang berarti program bantuan ini layak digunakan oleh nelayan. Nilai persepsi nelayan terhadap efektifitas program alat tersebut sebesar 5,26 yang berarti alat ini sangat cocok untuk nelayan. Nilai persepsi nelayan terhadap faktor kegunaan alat adalah 5,19 yang berarti alat ini sangat cocok untuk nelayan. Nilai persepsi nelayan terhadap bentuk alat pengering ikan adalah 4,19 yang berarti alat ini cocok untuk nelayan. Tabel distribusi frekuensi secara jelas dapat dilihat pada gambar 4.

The results of using fish dryers by the fishermen were also analyzed by frequency distribution. These results were obtained based on several criteria, such as the fishermen's perception of the tool, the appropriateness of the tool's use, the benefit factor, and the shape of the fish dryer. If viewed from the fishermen's perception of the tool, it gives an average value of 4.67, which means that this assistance program is suitable for fishermen. The value of fishermen's perceptions of the effectiveness of the tool program is 5.26, which means that this tool is very suitable for fishermen. The value of fishermen's perceptions of the tool's usefulness factor is 5.19, which means that this tool is very suitable for fishermen. The value of fishermen's perceptions of the shape of the fish dryer is 4.19, which means that this tool is suitable for fishermen. The frequency distribution table can clearly be seen in the Figure 4.

Figure 4. Fishermen's perception on the use of fish dryers

1. CONCLUSION

Pemanfaatan sistem PV pada pengering ikan dapat memenuhi kebutuhan energi listrik. Sistem PV ini dapat memenuhi 169,95% kebutuhan energi listrik 240 Wh/hari dari alat pengering ikan. Sistem PV dapat menghasilkan energi listrik sebesar 407,81 Wh/hari, dimana energi terbesar dapat mencapai 520 Wh dan terkecil 160,8 Wh. Perbedaan energi keluaran yang dihasilkan disebabkan oleh beberapa faktor lingkungan, antara lain suhu udara, kecepatan angin, dan kelembaban udara di sekitar lokasi pemasangan alat pengering ikan. Hasil analisis dampak penggunaan alat pengering ikan secara sosial dan ekonomi juga memberikan hasil yang signifikan (p < 0,005), dimana terjadi peningkatan dari sebelum dan sesudah penggunaan alat pengering ikan yang dialami oleh nelayan. Jika dilihat dari perspektif nelayan terhadap alat, ketepatan penggunaan alat, faktor manfaat, dan bentuk alat pengering ikan, para nelayan memberikan respon yang baik, dengan nilai rata-rata 4,19 - 5,26.

The utilization of PV systems in fish dryers can meet the needs for electrical energy. This PV system can meet 169.95% of the need for 240 Wh/day of electrical energy from fish dryers. PV system can produce electrical energy for 407.81 Wh/day, where the largest energy can reach 520 Wh and the smallest is 160.8 Wh. The difference in output energy produced is caused by several environmental factors, including air temperature, wind speed, and air humidity around the installation location of the fish dryer. The results of the analysis of the impact of using fish dryers socially and economically also gave significant results (p < 0.005), where there was an increase from before and after the use of fish dryers experienced by fishermen. When viewed from the perspective of fishermen on the tool, the accuracy of the use of the tool, the benefit factor, and the shape of the fish dryer, the fishermen gave a good response, with an average value of 4.19 – 5.26.

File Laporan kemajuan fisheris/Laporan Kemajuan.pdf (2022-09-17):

Pengisian poin C sampai dengan poin H mengikuti template berikut dan tidak dibatasi jumlah kata atau halaman namun disarankan seringkas mungkin. Dilarang menghapus/memodifikasi template ataupun menghapus penjelasan di setiap poin.

1. Pengumpulan Data
Kegiatan pengumpulan data dilakukan bersama mitra penelitian yaitu CV Ayu Nadi Group (Ayu Nadi). Pengumpulan data dilakukan di kantor pusat Ayu Nadi yaitu Jln. Gunung Soputan, Denpasar. Teknik pengumpulan data meliputi :
a. Focus Group Discussion (FGD)
FGD dilaksanakan oleh peneliti bersama manajer operasional, bagian pembelian, bagian keuangan, dan staf electronic data processing Ayu Nadi. Peneliti mengumpulkan kebutuhan informasi dalam mengukur kinerja bisnis Ayu Nadi yang selama ini menjadi acuan oleh pengambil keputusan Ayu Nadi. Kebutuhan informasi dari Ayunadi menjadi acuan dalam kebutuhan fungsional business intelligence system yang dibangun pada penelitian ini.

Gambar 1. FGD
b. Observasi
Pengumpulan data dengan teknik observasi dilakukan dengan melakukan pemantauan langsung pada struktur basis data yang terdapat pada RDBMS (Relational Database Management System) perusahaan Ayu Nadi. RDBMS yang digunakan pada Ayu Nadi adalah MS SQL Server 2012. Database operasional Ayu Nadi ditelaah untuk kebutuhan membangun data warehouse. Berikut merupakan tampilan RDBMS pada Ayu Nadi

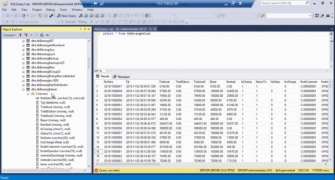
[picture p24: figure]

Gambar 2. RDBMS Ayu Nadi
c. Studi Pustaka
Metode ini merupakan kegiatan untuk menghimpun informasi yang relevan dengan topik atau masalah yang menjadi objek penelitian yang diperoleh dari buku-buku, jurnal, maupun internet. Pengumpulan data dengan metode ini dimaksudkan untuk membantu memperkuat landasan teoritis yang digunakan oleh penulis dalam penelitian ini.
2. Analisis Kebutuhan Sistem
Analisis kebutuhan sistem dilakukan untuk mengindentifikasi fungsi utama yang tersedia pada business intelligence system yang dibangun. Analisis kebutuhan sistem dilaksanakan berdasarkan pengumpulan data yang telah dilakukan. Berikut merupakan kebutuhan fungsional dari business intelligence system yang dibangun :
a. Sistem dapat menampilkan trend penjualan per bulan
b. Sistem dapat menampilkan trend penjualan per kuartal
c. Sistem dapat menampilkan top 10 dan bottom 10 laba per item
d. Sistem dapat menampilkan top 10 dan bottom 10 persentase per item
e. Sistem dapat menampilkan trend pembelian per bulan
f. Sistem dapat menampilkan trend pembelian per kuartal
g. Sistem dapat menampilkan top supplier
C. HASIL PELAKSANAAN PENELITIAN: Tuliskan secara ringkas hasil pelaksanaan penelitian yang telah dicapai sesuai tahun pelaksanaan penelitian. Penyajian meliputi data, hasil analisis, dan capaian luaran (wajib dan atau tambahan). Seluruh hasil atau capaian yang dilaporkan harus berkaitan dengan tahapan pelaksanaan penelitian sebagaimana direncanakan pada proposal. Penyajian data dapat berupa gambar, tabel, grafik, dan sejenisnya, serta analisis didukung dengan sumber pustaka primer yang relevan dan terkini.

h. Sistem dapat menampilkan retur barang per bulan
i. Sistem dapat menampilkan retur barang per kuartal
j. Sistem dapat menampilkan bad stock per bulan
k. Sistem dapat menampilkan bad stock per kuartal
l. Sistem dapat menampilkan perbandingan penjualan dan pembelian
m. Sistem dapat menampilkan perbandingan penjualan dan retur barang
n. Sistem dapat menampilkan perbandingan penjualan dan bad stock
3. Arsitektur Business Intellgence System
Pada sistem ini data source berasal dari 7 cabang Ayunadi Swalayan dan flat files data survey penjualan barang oleh Nielsen. Setiap cabang memiliki database POS Cashier dan Inventory. Pada database POS Cashier terdapat beberapa data seperti data penjualan, data kasir, detail penjualan dan tutup kas. Kemudian pada database inventory terdapat data inventory barang, kategori barang, pemesanan barang, penerimaan barang, retur barang, barang rusak. Dalam arsitektur business intelligence system terdapat proses ETL (extract, transform, load) yang bertujuan untuk melakukan penyerapan data dan transformasi data untuk dimasukan kedalam data warehouse. Data warehouse merupakan kumpulan data yang telah ditransformasi yang siap untuk dilakukan analisis. Data warehouse dimanfaatkan sebagai sumber data dalam visualisasi data, data mining, dan laporan kinerja perusahaan.

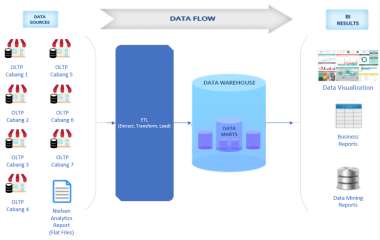
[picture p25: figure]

Gambar 3. Arsitektur Business Intelligence

4. Perancangan Data Warehouse
Perancangan data warehouse dalam penelitian ini menggunakan metode nine steps kimball yang dimulai dari proses choosing the process. Proses bisnis yang berhubungan dengan kebutuhan yang dipakai pada penelitian ini ditunjukan pada Tabel 1

Tabel 1 Choosing The Process
Proses Bisnis | Deskripsi
Transaksi penjualan | Proses untuk menyimpan semua transaksi penjualan
Transaksi pembelian | Proses untuk menyimpan semua transaksi pembelian
Retur Barang | Proses untuk menyimpan semua retur barang
Barang Rusak (Bad Stock) | Proses untuk menyimpan semua barang rusak

Proses selanjutnya adalah choose the grain yang merupakan penentuan apa yang akan dipresentasikan oleh tabel fakta data warehouse. Sesuai dengan kebutuhan fungsional yang didapat, informasi yang ditampilkan ditunjukan pada Tabel 2.

Tabel 1 Choosing The Grain
Grain | Deskripsi
Penjualan per Bulan | Jumlah penjualan dapat dilihat berdasarkan bulan
Penjualan per Kuartal | Jumlah penjualan dapat dilihat berdasarkan kuartal
Top dan Bottom 10 Laba per Item | Jumlah laba per item berdasarkan 10 item tertinggi dan terendah
Top dan Bottom 10 Persentase per Item | Jumlah persentase per item berdasarkan 10 item tertinggi dan terendah
Pembelian per Bulan | Jumlah pembelian dapat dilihat berdasarkan bulan
Pembelian per Kuartal | Jumlah pembelian dapat dilihat berdasarkan Kuartal
Top 10 Supplier | Jumlah supplier berdasarkan 10 supplier yang mendistribusikan paling banyak
Retur Barang per Bulan | Jumlah retur barang dapat dilihat berdasarkan bulan
Retur Barang per Kuartal | Jumlah retur barang dapat dilihat berdasarkan kuartal
Bad Stock per Bulan | Bad stock dapat dilihat berdasarkan bulan
Bad Stock per Kuartal | Bad stock dapat dilihat berdasarkan kuartal
Penjualan & Pembelian | Perbandingan jumlah penjualan & pembelian
Penjualan & Retur Barang | Perbandingan jumlah penjualan & retur barang
Penjualan & Bad Stock | Perbandingan jumlah penjualan & bad stock

Proses selanjutnya dalam data warehouse adalah menentukan tabel dimensi. Berdasarkan data yang diperlukan, tabel dimensi yang dihasilkan ditunjukan pada Tabel 3.

Tabel 2 Tabel Dimensi
Dimensi | Keterangan
Barang | Terdapat informasi tentang barang
Cabang | Terdapat informasi tentang cabang
Supplier | Terdapat informasi tentang supplier

Selanjutnya menentukan tabel fakta, berikut tabel fakta yang dihasilkan untuk memenuhi kebutuhan perusahaan retail dapat dilihat pada Tabel 4.

Tabel 3 Tabel Fakta
Fakta | Keterangan | Dimensi
Penjualan Barang | Terdapat informasi tentang jumlah dan total penjualan pada barang | Barang, Cabang
Penjualan Nota | Terdapat informasi tentang jumlah dan total penjualan pada transaksi | Barang, Cabang, Supplier
Pembelian Barang | Terdapat informasi tentang jumlah dan total pembelian pada barang | Barang, Cabang, Supplier
Pembelian Nota | Terdapat informasi | Barang, Cabang,

| tentang jumlah dan total pembelian pada transaksi | Supplier
Retur Barang Barang | Terdapat informasi tentang jumlah dan total retur barang pada barang | Barang, Cabang, Supplier
Retur Barang Nota | Terdapat informasi tentang jumlah dan total retur barang pada nota | Barang, Cabang, Supplier
Barang Rusak Barang | Terdapat informasi tentang jumlah dan total barang rusak pada barang | Barang, Cabang, Supplier
Barang Rusak Nota | Terdapat informasi tentang jumlah dan total barang rusak pada nota | Barang, Cabang, Supplier

Proses selanjutnya dilanjutkan dengan melengkapi tabel dimensi dengan atribut, type dan keterangannya masing – masing. Berikut detail dari tabel dimensi dapat dilihat pada Tabel 5.

Tabel 4 Detail Tabel Dimensi
Dimensi | Atribut | Type | Keterangan
Barang | sk_barang | integer | Primary key dimensi barang
Barang | barcode | varchar(100) | Menyimpan barcode barang
Barang | nama_barang | varchar(200) | Menyimpan nama barang
Barang | satuan | varchar(50) | Menyimpan satuan barang
Cabang | kode_cabang | varchar(2) | Primary key dimensi cabang
Cabang | cabang | varchar(100) | Menyimpan cabang
Supplier | sk_supplier | integer | Primary key dimensi supplier
Supplier | nama_supplier | varchar(100) | Menyimpan nama supplier
Supplier | alamat_supplier | varchar(100) | Menyimpan alamat supplier
Supplier | no_telepon_supplier | varchar(60) | Menyimpan nomer telepon supplier

Setelah itu melengkapi tabel fakta dengan atribut, type dan keterangannya masing – masing. Berikut detail dari tabel fakta dapat dilihat pada Tabel 6.

Tabel 5 Detail Tabel Fakta
Fakta | Atribut | Type | Keterangan
Penjualan Barang | sk_penjualan | integer | Primary key fakta penjualan barang
Penjualan Barang | nonota | varchar(15) | Menyimpan no nota
Penjualan Barang | hari | integer | Menyimpan hari penjualan barang

Penjualan Barang | bulan | integer | Menyimpan bulan penjualan barang
Penjualan Barang | tahun | integer | Menyimpan tahun penjualan barang
Penjualan Barang | namabarang | varchar(50) | Menyimpan nama barang penjualan barang
Penjualan Barang | satuan | varchar(10) | Menyimpan satuan penjualan barang
Penjualan Barang | qty | numeric | Menyimpan qty penjualan barang
Penjualan Barang | hargajual | numeric | Menyimpan harga jual penjualan barang

Berdasarkan identifikasi tabel fakta dan dimensi, selanjutnya dapat digambarkan skema data warehouse untuk menyimpan data transaksi tersebut. Terdapat tiga tabel dimensi yaitu tabel dimensi barang, tabel dimensi cabang dan tabel dimensi supplier. Selain itu terdapat delapan tabel fakta yaitu tabel fakta penjualan barang, tabel fakta penjualan nota, tabel fakta pembelian barang, tabel fakta pembelian nota, tabel fakta retur barang barang, tabel fakta retur barang nota, tabel fakta barang rusak barang, dan tabel fakta barang rusak nota. Melihat dari tabel dimensi dan tabel fakta tersebut, maka skema data warehouse yang akan digunakan adalah star schema. Untuk lebih jelasnya skema data warehouse dapat dilihat pada gambar 3.4.

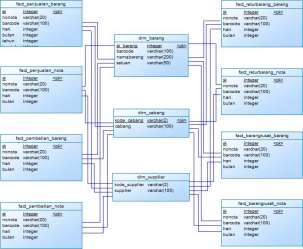
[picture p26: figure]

Gambar 3. 1 Skema Data Warehouse

5. Rancangan Proses Extract Transform Load
Pada proses ETL ini menggunakan tools Pentaho Data Integration dan menggunakan teknik batch processing, dimana data yang diimport akan melalui proses pengelompokan terlebih dahulu sesuai dengan jadwal yang sudah ditentukan. Setelah itu data tersebut akan melalui proses ETL yang dimulai dari proses data cleaning, dimana pada proses ini dilakukan penghapusan atau penghilangan data yang tidak terpakai agar data yang akan disimpan sesuai dengan apa yang diharapkan dan tidak terdapat redudansi data. Kemudian data transforming merupakan proses pengolahan data yang telah diextract, sehingga memiliki satu format yang sama. Dan yang terakhir data loading, dimana data yang telah selesai diproses kemudian akan disimpan ke dalam data warehouse. Data yang telah tersimpan di dalam data warehouse tersebut siap untuk divisualisasikan dalam bentuk grafik. Proses ETL dapat dilihat pada Gambar 5.


Gambar 2 Proses Extract Transform Load

6. Perancangan Modul Data Mining
Modul data mining pada business intelligence system yang dibangun bertujuan untuk memberikan informasi bagi perusahaan untuk menunjang kinerja perusahaan. Pada modul data mining terdapat aplikasi data mining berupa asosiasi barang. Data mining asosiasi barang memberikan luaran berupa pola belanja konsumen dalam membeli barang secara bersamaan. Informasi ini dapat menjadi dasar bagi mitra dalam menyusun strategi peletakan barang, promosi barang, dan cross selling strategy.


Gambar 6 Gambaran Umum Modul Data Mining Asosiasi

Gambaran umum sistem dari penelitian ini yaitu pengguna menyerap data fakta penjualan yang tersedia pada data warehouse. Kemudian dari dataset transaksi penjualan tersebut pengguna akan memasukkan parameter minimum support, minimum confidence, dan memilih dataset transaksi penjualan yang akan diproses. Sistem akan memproses parameter yang telah dimasukkan dan akan mengeluarkan informasi hasil aturan asosiasinya. Dari gambaran umum sistem ini akan digunakan sebagai acuan dalam membangun sistem pada penelitian ini.

a. Flowchart Penyerapan Data Fakta Transaksi Penjualan
Penyerapan data fakta transkasi penjualan bertujuan untuk pengambilan data fakta penjualan pada data warehouse untuk diproses oleh algoritma data mining asosiasi Apriori Hybrid. Gambar 7 menunjukan diagram alir penyerapan data fakta transaksi penjualan untuk modul data mining asosiasi.


Gambar 7 Flowchart Penyerapan Data Fakta Transaksi Penjualan

b. Flowchart Data Mining Analisis Asosiasi dengan Algoritma Hybrid
Pada Gambar 8, merupakan flowchart dari analisis algoritma apriori hybrid yang alurnya sebagai berikut:
i. Untuk proses pertama yaitu pengguna memilih menu analisis dataset transaksi, kemudian sistem akan menampilkan form data analisis transaksi dan pengguna akan memasukkan data parameter berupa minimum support, minimum confidence, dan dataset transaksi penjualan yang dipilih.
ii. | Kemudian sistem akan memproses dataset transaksi penjualan melalui iterasi pertama yaitu
| menghitung item-item dari support (transaksi yang memuat seluruh item) dengan memindai
| (scanning) database untuk 1-itemset, setelah 1-itemset didapatkan, dari 1-itemset apakah diatas
| minimum support, apabila telah memenuhi minimum support, 1-itemset tersebut akan menjadi
| frequent itemset yang tertinggi.
iii. | Dari iterasi tersebut akan didapat kembali database dataset transaksi penjualan berdasarkan
| Transaction ID (TID).
iv. | Setelah itu dilakukan iterasi kedua sehingga apabila frequent itemset tidak dapat dibentuk lagi
| maka akan menuju ke tahapan membentuk rule, menghitung confidence, dan menghitung lift
| ratio. Namun apabila frequent itemset masih dapat dibentuk maka dilakukan iterasi berikutnya.
v. Dari langkah tersebut, sistem akan menampilkan hasil analisis. Pengguna akan menekan
| tombol save jika ingin menyimpan hasil analisis tersebut. Jika tidak, maka sistem akan tetap
| menampilkan hasil analisis yang belum tersimpan.


Gambar 8 Flowchart Penyerapan Data Fakta Transaksi Penjualan

c. Pembangunan Aplikasi Data Mining dengan Metode CRISP-DM
Pembangunan aplikasi data mining dengan pendekatab metode CRISP-DM, memiliki enam fase yaitu fase pemahaman bisnis, pemahaman data, pengolahan data, pemodelan, evaluasi dan penyebaran.
i. Fase Pemahaman Bisnis (Business Understanding Phase)
Pada fase ini, penulis memahami alur bisnis serta permasalahan dari Ayu Nadi Swalayan. Pemahaman bisnis ini dilakukan agar didapat suatu pengetahuan tambahan mengenai alur bisnis dari Ayu Nadi Swalayan. Selain itu, pada tahapan ini, penulis menargetkan pembangunan sistem yang dapat menghasilkan sebuah informasi yang berguna bagi perusahaan.
ii. | Fase Pemahaman Data (Data Understanding Phase)
| Pada fase ini pengumpulan data terlebih dahulu dilakukan. Pengumpulan data
| dilakukan dengan mengambil data yang ada pada database dari Point of Sale (POS) Ayu Nadi
| Swalayan.
iii. | Fase Pengolahan Data (Data Preparation Phase)
| Pada fase ini dilakukan proses pemilihan dan pengolahan data yang nanti akan
| diperlukan dalam tahap selanjutnya. Pemilihan data ini, dilakukan dengan proses Extract
| Transform and Load (ETL) yang nantinya menghasilkan satu tabel berupa tabel barang, yang
| digunakan untuk proses mining.
iv. | Fase Pemodelan (Modeling Phase)
| Setelah data diolah, dilakukan proses pemodelan data. Pada penelitian ini model yang

digunakan yaitu asosiasi. Metode asosiasi ini digunakan karena data yang dihasilkan oleh Ayu Nadi Swalayan cocok digunakan untuk mencari keterkaitan barang yang sering dibeli secara bersamaan.
v. Fase Evaluasi (Evaluation Phase)
Pada fase ini, penulis menggunakan pengukuran lift ratio sebagai alat ukur untuk mengevaluasi keakuratan model atau metode asosiasi yang digunakan pada penelitian ini.
vi. | Fase Penyebaran (Deployment Phase)
| Fase ini adalah tahapan terakhir dimana peneliti menerapkan aplikasi pada komputer
| EDP Ayunadi Swalayan
d. Rancangan Antarmuka Aplikasi Data Mining
i. Rancangan Halaman Dataset Transaksi
| Halaman dataset transaksi merupakan halaman yang digunakan oleh pengguna untuk
| melihat file dataset transaksi yang sudah dilakukan proses import, dan digunakan untuk
| melakukan import dataset barang. Terdapat juga tombol refresh, yang digunakan apabila
| ketika proses import data yang sudah diproses tidak muncul. Halaman dataset transaksi
| penjualan dapat dilihat pada Gambar 9.

Gambar 9 Rancangan Antarmuka Data Fakta Transaksi

ii. Rancangan Halaman Analisis Asosiasi Halaman analisis asosiasi digunakan untuk menganalisis dataset transaksi menggunakan algoritma apriori hybrid. Pada halaman ini akan ditampilkan form untuk memasukkan data yang dibutuhkan saat memproses algoritma tersebut dan terdapat tombol simpan untuk menyimpan data hasil analisis. Halaman analisis dataset transaksi dapat dilihat pada Gambar 10


Gambar 10 Rancangan Antarmuka Data Fakta Transaksi

7. Perancangan Visualisasi Data
Dalam business intelligence system yang dibangun menampilkan visualisasi data sebagai bagian dalam business performance management. Visualisasi data menjadi instrument mitra yaitu Ayu Nadi dalam mengukur kinerja perusahaan. Pada kegiatan perancangan visualisasi data, disusun desain antarmuka sistem visualisasi data sebagai berikut :
i. Kinerja Penjualan Setiap Bulan
Halaman ini terdapat grafik yang menampilkan total penjualan berdasarkan bulan pada

Ayu Nadi Swalayan. Grafik penjualan setiap bulan dapat dilihat pada Gambar 11.


Gambar 11 Rancangan Antarmuka Kinerja Penjualan Setiap Bulan

ii. Kinerja Penjualan Setiap Kuartal Halaman ini terdapat grafik yang menampilkan total penjualan berdasarkan kuartal pada Ayu Nadi Swalayan. Grafik penjualan per kuartal dapat dilihat pada Gambar 12.


Gambar 12 Rancangan Antarmuka Kinerja Penjualan Setiap Kuartal

iii. Grafik Top & Bottom 10 Laba Item Terdapat dua grafik yang menampilkan top 10 laba per item dan bottom 10 laba per item pada Ayu Nadi Swalayan. Grafik top & bottom 10 laba per item dapat dilihat pada Gambar 13.


Gambar 13 Rancangan Antarmuka Grafik Top & Bottom 10 Laba Item

iv. Grafik Persentase Top & Bottom 10 Penjualan Item Terdapat dua grafik yang menampilkan top 10 persentase per item dan bottom 10 persentase per item pada Ayu Nadi Swalayan. Grafik top & bottom 10 persentase per item dapat dilihat pada Gambar 14.


Gambar 14 Rancangan Antarmuka Grafik Persentase Top & Bottom 10 Penjualan Item

v. Kinerja Pembelian Setiap Bulan
Halaman ini terdapat grafik yang menampilkan total pembelian berdasarkan bulan pada Ayu Nadi Swalayan. Grafik pembelian per bulan dapat dilihat pada Gambar 15.


Gambar 15 Rancangan Antarmuka Kinerja Pembelian Setiap Bulan

vi. Kinerja Pembelian Setiap Kuartal Halaman ini terdapat grafik yang menampilkan total pembelian berdasarkan kuartal. pada Ayu Nadi Swalayan. Grafik pembelian per bulan dapat dilihat pada Gambar 16.


Gambar 16 Rancangan Antarmuka Kinerja Pembelian Setiap Kuartal

vii. Grafik Top Supplier Halaman ini terdapat grafik yang menampilkan top supplier pada Ayu Nadi Swalayan. Grafik top supplier dapat dilihat pada Gambar 17.


Gambar 17 Rancangan Antarmuka Grafik Top Supplier

viii. Kinerja Retur Barang Setiap Bulan Terdapat grafik yang menampilkan total barang yang diretur berdasarkan bulan pada Ayu Nadi Swalayan. Grafik retur barang dapat dilihat pada Gambar 18.


Gambar 18 Rancangan Antarmuka Kinerja Retur Barang Setiap Bulan

ix. Kinerja Retur Barang Setiap Kuartal Terdapat grafik yang menampilkan total barang yang diretur berdasarkan kuartal pada Ayu Nadi Swalayan. Grafik retur barang dapat dilihat pada Gambar 19.


Gambar 19 Rancangan Antarmuka Kinerja Retur Barang Setiap Kuartal

x. Kinerja Bad Stock Setiap Bulan
Terdapat grafik yang menampilkan total barang yang rusak berdasarkan bulan pada Ayu Nadi Swalayan. Grafik retur barang per bulan dapat dilihat pada Gambar 20.


Gambar 20 Rancangan Antarmuka Kinerja Bad Stock Setiap Bulan

xi. Kinerja Bad Stock Setiap Kuartal Terdapat grafik yang menampilkan total barang yang rusak berdasarkan kuartal pada Ayu Nadi Swalayan. Grafik retur barang per kuartal dapat dilihat pada Gambar 21.


Gambar 21 Rancangan Antarmuka Kinerja Bad Stock Setiap Kuartal

xii. Komparasi Kinerja Penjualan dan Pembelian Terdapat grafik yang menampilkan perbandingan total penjualan dan pembelian pada Ayu Nadi Swalayan. Grafik penjualan & pembelian dapat dilihat pada Gambar 22.


Gambar 22 Komparasi Kinerja Penjualan dan Pembelian

xiii. Komparasi Kinerja Penjualan dan Retur Pembelian Terdapat grafik yang menampilkan perbandingan total penjualan dan retur barang. Grafik penjualan & retur barang dapat dilihat pada gambar 23.


Gambar 23 Komparasi Kinerja Penjualan dan Retur Pembelian

xiv. Komparasi Kinerja Penjualan & Bad Stock Terdapat grafik yang menampilkan perbandingan total penjualan dan bad stock. Grafik penjualan & bad stock dapat dilihat pada Gambar 24.


Gambar 24 Komparasi Kinerja Penjualan & Bad Stock

D. STATUS LUARAN: Tuliskan jenis, identitas dan status ketercapaian setiap luaran wajib dan luaran tambahan (jika ada) yang dijanjikan. Jenis luaran dapat berupa publikasi, perolehan kekayaan intelektual, hasil pengujian atau luaran lainnya yang telah dijanjikan pada proposal. Uraian status luaran harus didukung dengan bukti kemajuan ketercapaian luaran sesuai dengan luaran yang dijanjikan. Lengkapi isian jenis luaran yang dijanjikan serta mengunggah bukti dokumen ketercapaian luaran wajib dan luaran tambahan melalui Simlitabmas.
No. | Jenis Luaran | Keterangan
Kategori | Rencana Capaian | Capaian | Status Capaian | Target Capaian
1 | Artikel pada Conference/ Seminar Internasional di Pengindeks Bereputasi | Terbit dalam Prosiding | Prosiding Internasional | submited | TS | The 4th International Conference On Vocational Education And Technology -IConVET 2021 https://conferen ce.undiksha.ac.i d/iconvet/
2 | Artikel di Jurnal Nasional terakreditasi peringkat 1-3 | Accepted | Nasional Terakreditasi | draf | TS

3 Dokumen
pendaftaran hak
cipta

Terbit
Sertifikat

Draft manual
book
draf | TS


Gambar 25 Dokumen Bukti Pengajuan Artikel Pada Prosiding Internasional

E. PERAN MITRA: Tuliskan realisasi kerjasama dan kontribusi Mitra baik in-kind maupun in-cash (untuk Penelitian Terapan, Penelitian Pengembangan, PTUPT, PPUPT serta KRUPT). Bukti pendukung realisasi kerjasama dan realisasi kontribusi mitra dilaporkan sesuai dengan kondisi yang sebenarnya. Bukti dokumen realisasi kerjasama dengan Mitra diunggah melalui Simlitabmas.

Mitra pada skema penelitian PTUPT yang dilaksanakan adalah CV Ayu Nadi. CV Ayu Nadi memberikan kontribusi dalam bentuk data dan proses bisnis. Kontribusi dalam hal data direalisasikan dalam bentuk akses peneliti pada server basis data sistem informasi manajemen retail pada Ay Nadi Swalayan. Akses diberikan dalam bentuk remote desktop dan user SQL Server dengan akses read only. Gambar 26 merupakan aktivitas remote dekstop untuk menelaah basis data Ayu Nadi Swalayan.

Gambar 26 Pelaksanaan Remote Desktop Server Ayu Nadi Swalayan

Kontribusi mitra dalam hal proses bisnis berupa kegiatan Focus Group Discussion (FGD) membahas proses bisnis pada Ayu Nadi Swalayan. Pada kegiatan FGD selain membahas proses bisnis, dilakukan juga pembahasan kebutuhan akses informasi yang dapa dihasilkan oleh sistem untuk mempermudah dalam pengambilan keputusan. Gambar 27 merupakan realisasi kontribusi mitra pada kegiatan FGD.


Gambar 27 Pelaksanaan Diskusi Proses Bisnis Pada FGD Bersama Ayu Nadi Swalayan

F. KENDALA PELAKSANAAN PENELITIAN: Tuliskan kesulitan atau hambatan yang dihadapi selama melakukan penelitian dan mencapai luaran yang dijanjikan, termasuk penjelasan jika pelaksanaan penelitian dan luaran penelitian tidak sesuai dengan yang direncanakan atau dijanjikan.

Kesulitan atau hambatan yang dihadapi dalam proses pelaksaanaan penelitian dan mencapai luaran adalah terlambatnya penerimaan dana hibah penelitian dan pemberlakuan PPKM di Bali.

G. RENCANA TAHAPAN SELANJUTNYA: Tuliskan dan uraikan rencana penelitian di tahun berikutnya berdasarkan indikator luaran yang telah dicapai, rencana realisasi luaran wajib yang dijanjikan dan tambahan (jika ada) di tahun berikutnya serta roadmap penelitian keseluruhan. Pada bagian ini diperbolehkan untuk melengkapi penjelasan dari setiap tahapan dalam metoda yang akan direncanakan termasuk jadwal berkaitan dengan strategi untuk mencapai luaran seperti yang telah dijanjikan dalam proposal. Jika diperlukan, penjelasan dapat juga dilengkapi dengan gambar, tabel, diagram, serta pustaka yang relevan. Jika laporan kemajuan merupakan laporan pelaksanaan tahun terakhir, pada bagian ini dapat dituliskan rencana penyelesaian target yang belum tercapai.

Penelitian ini masih dalam tahap pelaksanaan. Rencana kegiatan yang akan dilakukan pada tahapan berikutnya adalah sebagai berikut:

1. Sinkronisasi data termutakhir dari Server Ayu Nadi ke VPS prototype sistem BI
2. Upgrade VPS untuk menampung data yang lebih besar dan peningkatan performa prototype sistem BI,
3. Melakukan uji coba tahap pertama untuk prototype sistem yang telah dibangun,
4. FGD bersama Ayu Nadi terkait prototype sistem BI,
5. Finalisasi draf buku manual untuk pengajuan HKI,
6. Mengajukan draf jurnal nasional ke penerbit,
7. Evaluasi kebutuhan sistem untuk rencana pengembangan tahun ke-2.
H. DAFTAR PUSTAKA: Penyusunan Daftar Pustaka berdasarkan sistem nomor sesuai dengan urutan pengutipan. Hanya pustaka yang disitasi pada laporan kemajuan yang dicantumkan dalam Daftar Pustaka.

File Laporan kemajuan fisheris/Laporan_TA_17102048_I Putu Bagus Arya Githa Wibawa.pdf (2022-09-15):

i

## TUGAS AKHIR

## RANCANG BANGUN AUTOMATIC SISTEM PENGERINGAN IKAN DENGAN PEMANTAUAN JARAK JAUH

I Putu Bagus Arya Githa Wibawa NIM. 17102048

Dosen Pembimbing I
I Gusti Made Ngurah Desnanjaya, M.T

Dosen Pembimbing II
I Nyoman Buda Hartawan, M.Kom

PROGRAM STUDI SISTEM KOMPUTER STMIK STIKOM INDONESIA
DENPASAR 2021

ii

HALAMAN INI SENGAJA DIKOSONGKAN

iii

HALAMAN PERSETUJUAN

Judul | : RANCANG BANGUN AUTOMATICSISTEM
| PENGERINGAN IKAN DENGAN
| PEMANTAUAN JARAK JAUH
Nama | : I Putu Bagus Arya Githa Wibawa
NIM | : 17102048
Program Studi : Sistem Komputer

Telah diperiksa dan disetujui sebagai Tugas Akhir mahasiswa Program Studi Sistem Komputer STMIK STIKOM Indonesia.

Menyetujui:

Mengetahui:
Kepala Program Studi Sistem Komputer

I Nyoman Buda Hartawan, M.Kom NIDN. 0809078602

Pembimbing II

I Nym Buda Hartawan, M.Kom NIDN. 0809078602

Pembimbing I

I Gst Md Ngurah Desnanjaya, M.T NIDN. 0820128802

iv

HALAMAN INI SENGAJA DIKOSONGKAN


v

Tanggal : 15 Juni 2021

vi

HALAMAN INI SENGAJA DIKOSONGKAN

vii

HALAMAN PERNYATAAN ORISINALITAS

Judul | : RANCANG BANGUN AUTOMATICSISTEM
| PENGERINGAN IKAN DENGAN
| PEMANTAUAN JARAK JAUH
Nama | : I PUTU BAGUS ARYA GITHA WIBAWA
NIM | : 17102048
Program Studi : Sistem Komputer

Dengan ini saya menyatakan bahwa Tugas Akhir ini merupakan hasil karya saya sendiri, semua sumber baik yang dikutip maupun dirujuk telah saya cantumkan dengan benar dan sepanjang pengetahuan saya juga tidak terdapat karya yang sama pernah ditulis atau diterbitkan orang lain. Apabila terdapat permasalahan terhadap isi dari Tugas Akhir ini maka akan menjadi tanggung jawab saya sepenuhnya.

Denpasar, 15 Juni 2021

( I Putu Bagus Arya Githa Wibawa)

viii

HALAMAN INI SENGAJA DIKOSONGKAN

ix

HALAMAN PERNYATAAN PERSETUJUAN PUBLIKASI TUGAS AKHIR UNTUK KEPENTINGAN AKADEMIS

Sebagai civitas akademik STMIK STIKOM Indonesia, saya yang bertanda tangan di bawah ini:

Nama | : I Putu Bagus Arya Githa Wibawa
NIM | : 17102048
Program Studi : Sistem Komputer
Jenis Karya : Tugas Akhir

Demi pengembangan ilmu pengetahuan, menyetujui untuk memberikan kepada STMIK STIKOM Indonesia Hak Bebas Royalti Nonekslusif (Non-exclusive Royalty-Free Right) atas tugas akhir saya yang berjudul:

RANCANG BANGUN AUTOMATICSISTEM PENGERINGAN IKAN DENGAN PEMANTAUAN JARAK JAUH

Beserta perangkat yang ada (jika diperlukan). Dengan Hak Bebas Royalti Non-ekskutif ini STMIK STIKOM Indonesia berhak menyimpan, mengalihmedia/formatkan, mengelola dalam bentuk pangkalan data (database), merawat, dan mempublikasikan Tugas Akhir saya tanpa meminta izin dari saya selama tetap mencantumkan saya sebagai penulis/pencipta dan sebagai pemilik Hak Cipta.

Demikian pernyataan ini saya buat dengan sebenarnya.

Dibuat di : Denpasar
Pada tanggal: 15 Juni 2021

Yang menyatakan

( I Putu Bagus Arya Githa Wibawa )

x

HALAMAN INI SENGAJA DIKOSONGKAN

xi

ABSTRAK

RANCANG BANGUN AUTOMATICSISTEM PENGERINGAN IKAN DENGAN PEMANTAUAN JARAK JAUH

Nama Mahasiswa : I Putu Bagus Arya Githa Wibawa
NIM | : 17102048
Program Studi | : Sistem Komputer
Dosen Pembimbing : I Gusti Made Ngurah Desnanjaya, M.T
| : I Nyoman Buda Hartawan,M.Kom

Abstrak
Proses pengeringan ikan umumnya membutuhkan waktu pengeringan 2 sampai 4 hari bergantung dari cuaca sekitar, ketebalan ikan serta dijemur tanpa pelindung sehingga rentan terkontaminasi hewan liar. Pada penelitian ini dibuat sebuah alat yang mampu membuat ikan kering lebih efektif serta melindungi ikan saat proses pengeringan berlangsung dan menampilkan hasil monitoring melalui aplikasi android.
Sistem dibangun menggunakan microcontroller arduino uno dan memudahkan pengguna dalam memonitoring proses pengeringan ikan dari jarak jauh menggunakan aplikasi android. Data monitoring disimpan secara real-time database di server thingspeak. Sistem pengeringan ikan ini mampu menghidupkan / mematikan lampu uv secara otomatis.Tujuan dari penelitian ini adalah untuk membandingkan kinerja proses pengeringan menggunakan alat dengan proses pengeringan ikan pada umumnya. Pengujian dilakukan dengan menggunakan garam dan tanpa garam. Hasil menunjukkan bahwa rata – rata kadar air ikan yang dihasilkan pada pengeringan ikan tanpa garam dengan alat, tanpa garam tanpa alat, dengan garam dan alat, dan dengan garam tanpa alat adalah 41,9%, 38,0%, 48,6%, 46,6%, telah mendekati standar yaitu 40% sesuai SNI-01-2721-1992.
Dari hasil penelitian ini menunjukkan bahwa alat mampu memonitoring kadar air, suhu udara, dan berat ikan dari jarak jauh serta mengeringkan ikan lebih efektif dibandingkan dengan cara konventional.

Kata Kunci: Arduino uno, thingspeak, real-time database, kadar air

xii

HALAMAN INI SENGAJA DIKOSONGKAN

xiii

ABSTRACT

RANCANG BANGUN AUTOMATICSISTEM PENGERINGAN IKAN DENGAN PEMANTAUAN JARAK JAUH

Author | : I Putu Bagus Arya Githa Wibawa
Student ID | : 17102048
Study Program | : Computer System
Supervisor | : I Gusti Made Ngurah Desnanjaya,M.T
: | I Nyoman Buda Hartawan,M.Kom

Abstract
The drying fish process generally requires a drying time from 2 to 4 days depending on the surrounding weather, the thickness of the fish and drying without protection that could be susceptible to contamination by wild animals. In this research, a tool can be able to make dried fish more effectively and protects fish during the drying process and displays monitoring results through an android application.
The system is built using the Arduino Uno microcontroller and easy to use for users to monitor the fish drying process remotely using an Android application. Monitoring data is stored in real-time database on thingspeak server. This fish drying system is able to turn on/off the UV lamp automatically. Purpose of this study to compare the performance of the drying process using a tool and with the fish drying process in general. The test was carried out with salt and without salt. The results showed that the average of the fish water content produced by drying fish without salt with tools, without salt without tools, with salt and tools, and with salt without tools were 41.9%, 38.0%, 48.6%, 46 ,6%, has approached the standard of 40% according to SNI-01-2721-1992.
The results in this research indicate that the tool is able to monitor water content, air temperature, and fish weight remotely and dry fish more effectively than conventional methods.

Keywords: Arduino uno, thingspeak, real-time database, kadar air

xiv

HALAMAN INI SENGAJA DIKOSONGKAN

xv

KATA PENGANTAR

Puji syukur dipanjatkan kehadapan Tuhan Yang Maha Esa karena berkat Rahmat-Nya, sehingga laporan tugas akhir dengan judul “Rancang Bangun Automatic Sistem Pengeringan Ikan Dengan Pemantauan Jarak Jauh” ini dapat terselesaikan tepat pada waktunya.
Penulis menyadari tanpa bimbingan dan dukungan dari berbagai pihak laporan ini tidak akan terselesaikan tepat waktu. Oleh karena itu, pada kesempatan ini penulis ingin mengucapkan terima kasih kepada:
1. Bapak I Dewa Made Krishna Muku, S.T., M.T., selaku Ketua STMIK STIKOM INDONESIA yang telah menyelenggarakan program pendidikan Teknik Informatika dengan konsentrasi Komputer Akuntansi Bisnis
2. Bapak I Nyoman Buda Hartawan M.Kom selaku Kepala Program Studi Sistem Komputer.
3. Bapak I Gusti Made Ngurah Desnanjaya, S.T., M.T selaku dosen pembimbing I yang telah banyak memberikan bimbingan dan saran yang sangat berguna dalam menyusun laporan tugas akhir ini.
4. Bapak I Nyoman Buda Hartawan, S.Kom., M.Kom selaku dosen pembimbing II yang telah banyak memberikan bimbingan dan saran yang sangat berguna dalam menyusun laporan tugas akhir ini.
5. Semua pihak yang terlibat yang tidak dapat penulis sebutkan satu persatu, penulis ucapkan banyak terima kasih atas segala dukungan, motivasi dan bantuannya selama ini.

Denpasar, 15 Juni 2021

Penulis

xvi

HALAMAN INI SENGAJA DIKOSONGKAN

xvii

DAFTAR ISI

HALAMAN PERNYATAAN PERSETUJUANPUBLIKASI

xviii

xix

4.5.2 Tampilan aplikasi mendapat data dari server thingspeak54

DAFTAR PUSTAKA
LAMPIRAN
BIODATA PENULIS

xx

HALAMAN INI SENGAJA DIKOSONGKAN

xxi

DAFTAR GAMBAR

Gambar 3. 1 Kondisi areal pengeringan didepan rumah nelayan………26

Gambar 4. 1 Pemasangan komponen sensor suhu dan sensor cahaya…37

Gambar 4. 9 Proses pengiriman data suhu dan berat ke server

xxii

Gambar 4. 19 Hasil pengujian pengiriman data ke server thingspeak...55

Gambar 4. 21 Hasil timbang berat ikan kerapu sebelum dikeringkan...56 Gambar 4. 22 Perbandingan perubahan suhu didalam ruang

Gambar 4. 23 Perbandingan suhu didalam ruang pengering dengan

Gambar 4. 24 Grafik hubungan antara berat ikan terhadap waktu

Gambar 4. 25 Hubungan antara suhu dan berat ikan terhadap waktu dengan kondisi ikan berada didalam ruang pengering...62 Gambar 4. 26 Perbandingan berat ikan pada 2 kondisi (didalam

Gambar 4. 27 Perbandingan kondisi fisik ikan pada 2 kondisi (didalam ruang pengering dan diluar ruangpengering)..64 Gambar 4. 28 Perbandingan berat ikan awal dengan kondisi

xxiii

DAFTAR TABEL

Tabel 4. 5 Perbandingan hasil pembacaan suhu menggunakan

Tabel 4. 6 Perbandingan antara suhu didalam ruang pengering

Tabel 4. 8 Hubungan antara suhu dan berat ikan terhadap waktu .........61

Tabel 4. 10 Perbandingan hasil pengukuran suhu saat proses

Tabel 4. 11 Perbandingan hasil pengukuran berat ikan saat proses

xxiv

HALAMAN INI SENGAJA DIKOSONGKAN

xxv

DAFTAR LAMPIRAN

Lampiran 1 Draft wawancara Lampiran 2 Dokumentasi observasi Lampiran 3 Schematic diagram Lampiran 4 Blok diagram
Lampiran 5 Script xml halaman utama

xxvi

HALAMAN INI SENGAJA DIKOSONGKAN

1

BAB I
PENDAHULUAN

### 1.1 Latar Belakang

Badung merupakan salah satu kabupaten di Provinsi Bali yang terkenal dengan tempat wisata, budayanya, dan perkembangan teknologinya seperti Badung smart city. Smart city merupakan salah satu program Kabupaten Badung yang memanfaatkan teknologi internet untuk mengelola daerah dan pemerintahannya. Hasil survey 2018 oleh Asosiasi Penyelenggara Jasa Internet Indonesia (APJII) menyatakan bahwa sebanyak 59% menggunakan internet berdasarkan penetrasi pengguna internet pada Provinsi Bali. Salah satu sektor yang dimiliki Kabupaten Badung ialah keindahan pantai yang menjadi daya tarik para wisatawan untuk berkunjung ke Bali. Kedonganan merupakan salah satu kelurahan yang berada di Kabupaten Badung dengan sektor perikanan dan pantainya yang menjadi salah satu penunjang perekonomian. Terdapat pasar ikan dan restaurant untuk menjual hasil tangkapan para nelayan. Berdasarkan data dari Asosiasi Penyelenggara Jasa Internet Indonesia (APJII), penetrasi pengguna internet berdasarkan pekerjaan rata rata 60% untuk para nelayan atau buruh nelayan dan pedagang kecil sudah menggunakan internet.
Penggaraman merupakan salah satu cara pengawetan yang dilakukan untuk mengurangi kadar air sampai batas tertentu guna memperpanjang waktu simpan. Pengeringan merupakan terjadinya penguapan air ke udara akibat perbedaan kandungan uap air antara udara dan bahan yang dikeringkan. Pengeringan ikan merupakan salah satu usaha pengolahan ikan dengan cara menjemur ikan dibawah terik matahari untuk mengurangi kadar air dalam ikan. Ikan dijemur oleh nelayan/pedagang dengan kondisi tanpa perlindungan sehingga rentan terkontaminasi dengan debu dan serangga.
Dilansir dari jejaring sosial instagram Kementerian Kelautan dan Perikanan (KKP) Republik Indonesia, dinyatakan bahwa ikan yang telah diasinkan dapat menghambat pertumbuhan bakteri dalam daging ikan, dengan kadar garam yang tinggi akan menghentikan proses autolysis pada ikan, yang merupakan proses penghancuran sel yang dilakukan oleh enzim dalam sel itu sendiri. Dilansir dari website resmi Kementerian Kelautan dan Perikanan (KKP) Republik Indonesia, NTT merupakaan pengekspor ikan kering terbesar dan mengekpor hasil ikan kering ke negara Timor Leste, Jepang Thailand, Malaysia, Australia mencapai 115,3 ton per Semester I 2018, dengan menggunakan jalur darat dan transit jalur laut. Ini merupakan potensi besar untuk industri ikan

2

kering, dan tantangan untuk melakukan inovasi pembuatan alat pengeringan ikan yang efektif dan efisien.
Berdasarkan hasil observasi lapangan dan wawancara lisan dengan nelayan yang bernama Ibu Fatimah selaku pedagang ikan yang melakukan pengeringan untuk menambah penghasilan. Ikan akan disimpan jika tidak terdapat sinar matahari. Proses pengeringan dilakukan selama 2-4 hari dengan cara menjemur langsung dibawah terik sinar matahari di pesisir pantai, beliau juga menambahkan komunikasi yang dilakukan antar nelayan, pendagang, dan pembeli menggunakan media smartphone. Menurut (Ahmad Edi Waluyo dkk., 2017), secara kualitas tingkat kehigienisan ikan berkurang, sedangkan secara kuantitas waktu yang lama pada proses pengeringan ikan akan bergantung pada kondisi cuaca sekitar. Dari permasalah tersebut, diperlukan alat yang mampu melakukan proses pengeringan dengan efektif, higienis, dan memonitor suhu dan berat ikan secara real-time. Maka dari itu, dirancangnya sebuah sistem yang dapatmengeringkan ikan secara efektif dan higienis sehingga kualitas ikan tetap terjaga, dengan diletakkan pada rak yang telah dirancang dan berisikan sistem.
Alat pengering ikan ini dilengkapi sistem otomatis, yaitu ketika cuaca disekitar cenderung gelap, maka sensor LDR (Light Dependent Resistor) akan merespon untuk penyalaan lampu UV dan memulai proses pengeringan. Energi dihasilkan dari kolektor panel surya yang akan disimpan pada battery Aki, kemudian disalurkan pada perangkat microcontroller arduino, lampu UV, modul gsm sim 900, dan pada sensor yang digunakan. Sistem akan mengirimkan data ke aplikasi dan memberikan informasi kepada nelayan dengan perantara modul gsm sim
900. Berdasarkan data tersebut, penulis akan merancang bangun sistem yang berjudul “Rancang Bangun Automatic Sistem Pengeringan Ikan dengan Pemantauan Jarak Jauh”, yang diharapkan dapat mengoptimalkan produksi ikan kering para nelayan dan menjaga kehigienisan produk..

### 1.2 Rumusan Masalah

Rumusan masalah pada penelitian ini adalah sebagai berikut:
1) Bagaimana merancang bangun alat pengeringan ikan menggunakan sistem otomatis dengan pemantauan jarak jauh?
2) Bagaimana unjuk kerja alat pengeringan ikan menggunakan sistem otomatis dengan pemantauan jarak jauh?

### 1.3 Batasan Masalah

Batasan masalah pada penelitian ini adalah sebagai berikut:
1) Alat mampu menampung 1 kilogram ikan,

3

2) Alat mampu mengukur suhu udara sekitar dan berat ikan,
3) Alat mampu memonitoring kondisi suhu dan berat ikan secara realtime dan ditampilkan melalui aplikasi android,
4) Aplikasi android dapat diakses darimana saja dan kapan saja melalui koneksi internet,
5) Pemrosesan alat menggunakan Arduino uno,
6) Koneksi wireless menggunakan modul sim900,
7) Database sistem menggunakan platform thingspeak,
8) Nyala dan mati lampu UV dikendalikan otomatis menggunakan relay,
9) Jenis ikan yang digunakan adalah ikan kerapu yang telah dibelah dua dan diletakkan secara manual.
10) Tipe lampu UV yang digunakan adalah lampu UV-A,
11) Selama proses pegeringan, ikan tidak dibolak balik secara otomatis,
12) Setelah ikan kering, ikan diambil secara manual,
13) Penentuan kehigienisan objek penelitian dilakukan dengan cara melihat kondisi fisik ikan,
14) Parameter pengujian alat yang diukur adalah suhu udara sekitar dan berat ikan,
15) Pengujian aplikasi android yaitu menggunakan model pengujian fungsional black box testing.

### 1.4 Tujuan Penelitian

Tujuan dari penelitian ini adalah sebagai berikut:
1) Merancang bangun alat pengeringan ikan menggunakan sistem otomatis denganpemantauanjarakjauh.
2) Menjelaskan bagaimana unjuk kerja dari alat pengeringan ikan menggunakan sistem otomatis dengan pemantauan jarak jauh.

### 1.5 Manfaat Penelitian

Adapun manfaat dari penelitian ini sebagai berikut:
1) Bagi Masyarakat
Membantu dan memudahkan nelayan/padagang ikan kering dan masyarakat agar dapat mengeringkan ikan secara praktis.
2) Bagi Instansi
Diharapkan bisa menjadi referensi akademik dan juga menjadi sarana pembelajaran dalam peningkatan kualitas di masa yang akan datang.
3) BagiPenulis
Dapat menerapkan ilmu-ilmu yang diperoleh selama perkuliahan dan juga untuk menambah wawasan dan pengetahuan dalam pembuatan sebuah hasil karya ilmiah.

4

### 1.6 Sistematika Penulisan

Berikut adalah sistematika penulisan pada laporan penelitian ini,

BAB I PENDAHULUAN
Dalam bab ini dijabarkan tentang latar belakang, rumusan masalah, batasan masalah, tujuan penelitian, manfaat penelitian dan sistematika penulisan.

BAB II TINJAUAN PUSTAKA
Dalam bab ini mengulas tentang penelitian serupa yang pernah dilakukan serta teori-teori terkait alat pengeringan ikan.

BAB III ANALISIS DAN PERANCANGAN
Dalam bab ini mengulas mengenai metode yang dilakukan selama proses penelitian, mulaidaripengumpulan data, perancangan, hingga pembuatandesign.

BAB IVIMPLEMENTASI DAN PEMBAHASAN
Dalam bab iniakan diuraikan secara detilmengenaisistemyangakan dibuat dan hasilpembuatansistembeserta pengujuannya.

BAB V PENUTUP
Dalambab iniberisisimpulandansaranmengenaiperancangansistem yangdibuat.

5

BAB II
TINJAUAN PUSTAKA

### 2.1 Penelitian terdahulu

Penelitian yang akan dilakukan oleh penulis adalah membuat sebuah sistem yang akan melakukan pengeringan ikan, jenis ikan kerapu dengan menggunakan bantuan sinarlampu UV ketika tidakada cahaya matahari dan dapatdimonitoring menggunakan smartphone. Menggunakan solar panel untukmengecas accumelaluicharger controller. Penelitian ini bertujuan untuk mendapatkan hasil yang optimal dalam proses mengeringkan ikan, serta mengetahui perbedaan proses pengeringan dengan sinarmataharitanpa dilindungi dibandingkandengan menggunakan lampu UV dan dilindungi dengan plastik uv. Adapun penelitian terdahulu sebagai berikut;
Pada penelitian pertama, yang dilakukan oleh (Lukmansyah dkk., 2019) dengan judul “Pengembangan Sistem Pengeringan Ikan Asin Otomatis Dengan Pemantau Nirkabel”. Objek yang diteliti adalah ikan bawal, dengan parameter yang akan diteliti adalah biaya pemakaian listrik, berat ikan, waktu pengeringan, suhu ruang pengering. Metode penelitian yang digunakan adalah Alat yang berbentuk kotak dirancang untuk mengefisiensikan waktu yang dibutuhkan saat proses pengeringan ikan asin dengan menggunakan Arduino Uno sebagai microcontroller. Sistem ini juga dapat dipantau melalui smartphone menggunakanMIT App Inventor. Alat ini menggunakan listrik dari PLN sebagai sumber daya, kemudian disalurkan ke blower untuk mela ngsungka n proses pengeringan. Ketika blowerterhubung dengan listrik dan dinyalakan, maka kipas akan menghisap udara di sekitar dan masuk ke dalam perangkat blower, kemudian diproses di bagian elemen panas, sehingga hembusan udara yang keluar akan menghasilkan suhu lebih tinggi atau panas. Hasil yang diperoleh adalah Sistem pengering ikan asin yang dirancang ini dapatmengefisienkan waktu yangdibutuhkan untuk pengeringan ikan dibandingkan dengan pengeringan ikan secara tradisional. Alat dapat dipantau pada smartphone untuk mengetahui berat ikan asin yang ada di dalam kotak pengering secara real time mengguna ka n MIT App Inventor.
Pada penelitian kedua, yang dilakukan oleh (Hatta dkk., 2019) dengan judul “Sistim Pengeringan Ikan Dengan Metode Hybrid”. Objek yang diteliti adalah ikan karang dan ikan teri, dengan parameter yang akan diteliti adalah Berat ikan, Waktu pengeringan, Penurunan kadar air, Intensitas cahaya matahari. Metode penelitian yang digunakan adalah

6

Sistem Pengeringan dengan metode hybrid merupakan sistem pengeringan yang menggunakan dua atau lebih sumber energi untukproses penguapan air. Sistem mengubah pancaran sinar matahari menjadi energi panas melalui collector surya, kemudian diteruskan ke seluruh bagian ruang pengering sehingga terjadi akumulasi energi di dalam ruang pengering dan menyebabkan suhu meningkat, kenaikan suhu ruang akan menguapkan airyang terkandung dalam bahan. Bahan bakar gas sebagaisumber energi kedua yang akan memanaskan ruang untuk mengeringkan bahan apabila radiasi matahari berkurang atau tidak ada. Tujuan dari penelitian yang dilakukan oleh penulis adalah untuk meningkatkan temperatur udara panas ruang pengering hybrid, melakukan optimalisasi waktu pengeringan dan menghitung kadar air pada ikan. Hasil yang diperoleh adalah pengeringan dengan cara tradisional membutuhkan waktu sekitar 3 hari dengan kondisi cuaca cerah dan intensitas cahaya matahari yang tinggi, setelah menggunakan energi hybrid (energi surya dan energi bahan bakar gas) waktu pengeringan relatif lebih singkat yaitu 13 jam untuk pengeringan ikan karang dan 8,5 jam untuk pengeringan ikan teri.
Pada penelitian ketiga, yang dilakukan oleh (Djamalu, 2016) Dengan judul “Peningkatan kualitas ikan asin dengan proses pengeringan efek rumah kaca variasi hybrid”. Objek yang diteliti adalah ikan layang, dengan parameter yang akan diteliti adalah Panas yang tersimpan pada ruang pengering yang dihasilkan dari variasi hybrid, dan performansi perpindahan panas dan laju pengeringan pada proses pengeringan. Metode penelitian yang digunakan adalah Alat yang digunakan adalah pengering efek rumah kaca, timbangan analitis, alat ukur termometer untuk mengukur suhu pada dinding bagian luar dan dalam, rak satu, rak dua, rak tiga, batu penyimpan panas, suhu pada ruang pengering dan suhu pada permukaan ikan asin, oven untuk mengukur kadar air awal dan akhir ikan asin selama proses pengeringan, alat ukur termometer bola basah dan termometer bola kering untuk mengukur kelembaban di dalam pengering dan data intensitas matahari, suhu lingkungan dan kelembaban relatif lingkungan dari data BMKG Gorontalo.
Hasil yang diperoleh adalah Perpindahan panas terbesar pada pengering perpindahan panas konveksi pada hari ke-2 yakni 33292 W/m².k untuk konveksi dari rak pengering ke ruang pengering dan 1804 W/m².k untuk konveksi dari batu ke ruang pengering, untuk laju perpindahan panas yang berguna pada penguapan kadar air (Qe) terbaik sesuai analisis adalah pada hari ke-2 dimana Qe 2360,4 J/m².s dan berat terevaporasi (Mev) tertinggi pada hari ke-1 yakni 2,8183 kg. Berat awal ikan asin sebelum dilakukan proses pengeringan adalah 8 kg, penurunan

7

berat terbesar adalah pada hari ke- 2 yakni 3.848 kg dan untuk penurunan kadar air akhir ikan asin yang paling besar adalah pada hari ke- 2 yaitu dari 68,86 % menjadi 40,2 % yang artinya nilai tersebut hampir mendekati 40 % sesuai standart SNI nomor 01-2721-1992, waktu pengeringan di lakukan selama 9 jam yaitu dari jam 09.00 sampai dengan 17.00 WITA sedangkan berat terevaporasi (Mev) pengeringan yang diperoleh dari hasil analisis lebih rendah dari pada pengukuran berat yang diperoleh pada saat uji coba.

### 2.2 Penggaraman

Berdasarkan (Kementerian Kelautan & Perikanan Republik Indonesia, 2015) penggaraman ikan merupakan cara pengawetan ikan yang banyak dilakukan diberbagainegara.Ikan yangdiawetkan dengan garam disebut ikanasin.Garamyangdipakaiadalah garam dapur(NaCl), baik yang berupa kristal maupun yang berupa larutan. Fungsi pengawet yangdilakukan olehgaramberjalanmelalui:
1) Menunda autolysis,
2) Membunuh bakterisecara langsung.

Kematian bakteri dalam proses penggaraman disebabkan oleh kejadian – kejadian berikut:
1) Garam menyerap air dari tubuh ikan melalui proses osmosa. Akibatnya, air yangtersedia bagibakteriberkurang. Kekuranganair di sekitarbakteriitumenyebabkan metabolismebakteriterganggu,
2) Garam juga menyerap air dari tubuh bakteri itu sendiri. Bakteri mengalamiplasmolysis(pemisahanintiplasma/pecahnya dinding sel) sehingga mati.

### 2.3 Pengeringan

Pengeringan adalah terjadinya penguapan air ke udara karena perbedaan kandungan uap air antara udara dengan bahan yang dikeringkan. Tujuan pengeringan adalah untuk mengurangi kadar air bahan sampai batas perkembangan mikroorganisme dan kegiatan enzim yang dapat menyebabkan pembusukan terhambat atau bahkan terhenti sama sekali. Pengeringan ikan sebagai salah satu cara pengawetan yang paling mudah,murah dan merupakan cara pengawetan yang tertua. Pada prinsipnya pengeringan merupakan cara pengawetan ikan dengan mengurangikandungan air daribahan. Pengeringan akan bertambahbaik dan cepat apabila sebelumnya ikan digarami dengan jumlah garam yang cukup untuk menghentikan kegiatan bakteri pembusuk (Kementerian Kelautan & Perikanan Republik Indonesia, 2015).

8

Pengeringan ikan adalah proses penguapan air dari permukaan ikan yang dikeringkan dengan tidak mengubah sifat kimia dari ikan tersebut. Proses pengeringan ikan terdiridari dua cara yaitu pengeringan alamidanpengeringanbuatan.Keduapengeringinimemiliki kelemahan dan kelebihan. Kelemahan dari pengering alami ialah waktu pengeringan tergantung dengan kondisi cuaca dan butuh waktu yang lama untuk mengeringkan ikan. Sedangkan pengering buatan dapat tidak ketergantungan dengan kondisi cuaca serta waktu proses pengeringan tidak lama. Proses pengeringan ikan yangdilakukan paranelayan diNTT dengan menggunakan panas matahari, dimana suhuudara pada sianghari rata-rata 30o

c - 33,7o
c. Sehingga energi panas matahari sangatpotensial untuk dimanfaatkan untuk memproduksi ikan kering. Kadar air ikan kering rata-rata 20% - 35 % dengan waktupengeringan 5 – 8 hari. Akan tetapi kendala yang timbul akibat lamanya pengeringan yaitu terjadinya kerusakan ikan dan higenitas ikan kurang baik karena terkontaminasi dengan debu, lalat dan kotoran lainnya (Sirait, 2019).

### 2.4 Platform thingspeak

Thingspeak merupakan penyedia layanan analisa Internet of Things(IoT) yang dapat memvisualisasikan, menganalisis data secara real time dengan komputasi awan. Thingspeak dapat berinteraksi dengan perangkat raspberry Pi, ESP8266, Arduino dan Matlab. Thingspeak menyediakan API untuk mengakses data channel yang telah dibuat. Gambar 2.1 merupakan gambar logo dari platformthingspeak.

(Sumber:https://thingspeak.com/id/abou)

### 2.5 Sistem android

Android adalahsebuahsistem operasiperangkatmobile berbasis linux yang mencakup sistemoperasi, middleware dan aplikasi. Android menyediakan platform terbukabagi para pengembang untuk menciptakan aplikasiyangakandibuat.Androiddikembangkandenanberbagaiversi dan fituryangtersedia (Karman dkk., n.d.).Gambar 2.2 merupakan icon dari sistem android.

Gambar 2. 1 Logo thingspeak


9

### 2.6 Aplikasi android studio

Berdasarkan (Karman dkk., n.d.) pengertian Android studio adalah IDE (Integrated Development Environtment) resmi ntuk pengembangan aplikasiAndroid dan bersifat open sourceataugratis. Pada gambar 2.3 merupakan icon aplikasi android studio. PeluncuranAndroid Studio inidiumumkanoleh Google pada16Mei2013pada eventGoogle I/O Conferenceuntuk tahun 2013. Aplikasi android studio sangat berguna untuk para developer android dengan kode program java dan kotlin. Adapun fitur yangdimiliki oleh Android Studioseperti;
1) Projek berbasis pada GrandleBuild
2) Refactory danpembenaan bugyangcepat
3) Tools baru yangbernama‘Lint’ diklaimdapatmemonitor kecepatan kegunaan,serta kompetibelitas aplikasidengan cepat.
4) Mendukungproguarddanapp-signinguntukkeamanan.
5) Memiliki GUI aplikasi android lebihmudah.
6) Didukung oleh Google Cloud Platform untuk setiap aplikasiyang dikembangkan.

### 2.7 Software IDEArduino

Software IDE (Integrated Development Environment) Arduino berguna untuk membuat, membuka, dan mengedit source code Arduino

Gambar 2. 2 Icon android

Gambar 2. 3 Aplikasi android studio

10

(Sketches, para programmer menyebut source code yang ditulis dengan istilah ”sketches”). Sketchmerupakan sourcecode yangberisilogika dan algoritma yang akan diupload ke dalam IC mikrokontroller (Arduino) (Santoso, n.d.). Software Arduino ini perlu instalasi extra jika ingin menginstall di Linux, tidak seperti proses instalasi pada Windows dan Mac. Pada gambar 2.4 merupakan tampilan utama aplikasi kode editor arduino IDE. Berikut bagian – bagian IDE Arduino, dan tampak interface Arduino IDE.
1) Verify pada versi sebelumnya dikenal dengan istilah Compile. Sebelum aplikasi di-upload ke board Arduino, biasakan untuk memverifikasi terlebih dahulu sketch yang dibuat. Jika ada kesalahan pada sketch, nanti akan muncul error. Proses Verify / Compile mengubah sketch ke binary code untuk di-upload ke mikrokontroller.
2) Upload tombol ini berfungsi untuk mengupload sketch ke board Arduino.Walaupunkitatidakmengkliktombol verify,makasketch akan di-compile, kemudian langsung diupload ke board. Berbeda dengan tombol verify yang hanya berfungsi untuk memverifikasi source codesaja.
3) NewSketch Membuka windowdanmembuatsketchbaru.
4) Open SketchMembuka sketchyangsudahpernahdibuat.Sketch yang dibuat dengan IDE Arduino akan disimpan denganekstensi file .ino
5) Save Sketch menyimpan sketch, tapi tidak disertai dengan mengkompile.
6) Serial Monitor Membuka interface untuk komunikasiserial, nanti akan kita diskusikanlebih lanjut padabagianselanjutnya.
7) Keterangan Aplikasi pesan-pesan yang dilakukan aplikasi akan muncul di sini, misal “Compiling” dan “Done Uploading” ketika kita mengcompile danmenguploadsketchkeboard Arduino
8) Konsol log Pesan-pesan yang dikerjakan aplikasi dan pesan-pesan tentang sketch akan muncul pada bagian ini. Misal, ketika aplikasi mengcompile atau ketika ada kesalahan pada sketchyang kita buat, maka informasierror dan baris akandiinformasikandibagianini.
9) Baris Sketch bagian iniakan menunjukkan posisibaris kursor yang sedang aktif pada sketch. Informasi Board dan Port Bagian ini menginformasikan port yangdipakaiolehboardArduino.

11

(Sumber://https://books.google.co.id)

### 2.8 Load Cell

Sensor loadcell merupakan sensor yang dirancang untuk mendeteksi tekanan atau berat sebuah beban, sensor loadcell umumnya digunakan sebagai komponen utama pada sistem timbangan digital dan dapat diaplikasikan pada jembatan timbangan yang berfungsi untuk menimbang berat dari truk pengangkut bahan baku, pengukuran yang dilakukan oleh loadcell menggunakan prinsip tekanan. Gambar 2.5 merupakan sensor loadcell, untuk mengakses sensor loadcell diperlukan modul hx711. Sensor loadcell merupakan sensor berat, apabila loadcell diberibeban pada intibesinya maka nilai resitansi di strain gauge akan berubah (Lukmansyah dkk.,2019).

(Sumber: http://m.id.qye-sensor.com/load-cell/)

Gambar 2. 4 Tampilan software IDEArduino

Gambar 2. 5 Sensor loadcell

12

### 2.9 Ds18b20

Sensor Ds18b20 merupakan sensor suhu digital yang di dalamnya sudah terdapat ADC (Analog to Digital Converter) dengan resolusi 12 bit. Sensor ini memiliki tingkat keakuratan dan kestabilan yang cukup baik dibandingkan dengan sensor suhu LM35DZ yang biasa digunakan. Sensor Ds18b20 memiliki tingkat akurasi yang cukup tinggi yaitu 0,5 pada rentang suhu-10˚C - 85 ˚C dan secara keseluruhandapat mengukur dari-55˚C - 125˚C. Sensorsuhu Ds18b20memiliki 3 pin yang terdiridari +5 V, ground dan input/output. SensorDs18b20memiliki dua jenis casing,yangumumberedardipasaranyaitucasingbiasa dancasing anti air (Lukmansyah dkk., 2019). Gambar 2.6 merupakan sensor suhu DS18b20 memiliki sensitivitasnya tidakterlalu tinggidan bersifat digitalsehingga tegangan yang dihasilkan oleh sensor suhu DS18B20 tidak perlu dikonversi. Berikut pada gambar 2.6 merupakan bentukfisikdarisensor Ds18b20(Ekayana, 2020).

Gambar 2. 6 Sensor Ds18b20 (Sumber: https://components101.com/sensors/ds18b20-temperature-sensor) (https://components101.com/sensors/ds18b20-temperature-sensor)

### 2.10 Aplikasi eagle

Aplikasi eagle adalah perangkat lunak electronic design automation (EDA) yang memungkinkan perancang printed circuit board (PCB) menghubungkan diagram skematik, penempatan komponen,
perutean | PCB, | dan | konten | pustaka | yang | komprehensif
(www.autodesk.com, 2020).Pada gambar 2.7 merupakan tampilan utama dari aplikasi eagle. Aplikasi eagle memudahkan pengguna dalam pembuatan jalur pcb dan membuat schematicrangkaian elektronika.


13

### 2.11 Light dependent resistor

LDR (Light Dependent Resistor) adalah suatu jenis resistor dimana nilai resistansinya tergantung pada intensitas cahaya yang diterimanya. Nilai hambatan LDR turun hingga 500 Ω pada saat cahaya terang dan naikmencapai200 kΩ pada dalamkondisigelap (Paramytha dan Kasim, 2018).Gambar 2.8 merupakan sensor ldr beserta modulnya.

(Sumber: https://www.google.com/ldr+sensor) (https://www.google.com/search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)

### 2.12 Modul SIM900

Sim900 dari Simcom adalah contoh dari gsm modul tersebut. Kemampuannya untuk bekerja pada mode voice,CSD, dan data GPRS. m900 sebagai alat komunikasi antara pengirim dan penerima. ComSat SIM900 adalah GSM/GPRSShield untuk Arduino yangberdasarkan atas modul SIM900 Quad-band GSM/GPRS. Dikendalikan menggunakan AT commands (GSM 07.07, 07.05 dan AT commands SIMCOM yang lebih ditingkatkan) dan cocok (compatible) dengan board Arduino (Uno dan Mega 2560)(Hermono dkk., 2015).

Gambar 2. 7 Aplikasi eagle

Gambar 2. 8 Sensor LDR

14

### 2.13 Buck converter

Seri regulator LM2596 bersifat monolitik sirkuit terintegrasi yang menyediakan semua fungsi aktif untuk regulator switching step- down (buck), yang mampu dijalankan beban 3A dengan pengaturan saluran dan beban yang luar biasa. Seri LM2596 beroperasi pada frekuensi switching 150kHz, sehingga memungkinkan filter berukuran lebih kecil.Pada gambar 2.9 merupakan modul buck convertertanpa lcd output analog.

(Sumber: https://www.google.com/buck+converter) (https://www.google.com/search?q=buck+converter&tbm=isch&biw=1600&bih=795)

### 2.14 Aplikasi blender

Blender adalah aplikasi pembuatan 3D open source dan free. Aplikasi ini mendukung keseluruhan pemodelan 3D, rigging, animasi, simulasi, rendering, compositing, motion tracking, mengedit video dan pembuatan game.Bagipengguna yangmahir dapatmenggunakanAPI dari Blenderdalammenyesuaikan aplikasibahkanmembuatspesialtoolsdengan script Python. Aplikasi blender bersifat cross-platform yang artinya dapat berjalandisistemoperasimanapunbaikdiLinux,Windows dan Macintosh. Interfacenya menggunakan OpenGL untuk memberikan kesan yang konsisten. Blender memiliki foundation yang diberi nama Blender Foundations (2002) yang merupakan organisasi kemaslahatan publik yang independent. Blender Foundations termasuk dalamanggota Open Invention Network, Khronos, Linx Foundation, dan Academy Dortware Foundation. Sebagai proyek yang berbasis komunitas di bawah GNU GeneralPublic License (GPL), publik diberiwewenang untuk melakukan perubahan kecildanbesarpada basis kode,yangmengarahpada fitur-fitur baru, perbaikan bugyangresponsif, dankegunaan yanglebih baik. Blender tidak memiliki label harga, tetapi pengguna dapat berinvestasi, berpartisipasi, dan membantu memajukan blender (“About - Blender,” n.d.). Gambar 2.10 merupakan tampilan utama dari aplikasi pengolah gambar 3D yaitu aplikasi blender.

Gambar 2. 9 Step down buck converter LM2596

Gambar 2. 10 Aplikasi blender

15

### 2.15 LCD 16x2

Layar LCD merupakan media penampil data yang sangat efektif dalam suatu sistem elektronik. Agar sebuah pesan atau gambar dapat tampil pada layar LCD, diperlukan sebuah rangkaian pengatur scanning dan pembangkit tegangan sinus. Rangkaian yang cukup rumit ini awalnya sering menjadi kendala bagi pemula elektronika dalam menggunakan layar LCD. Beberapa perusahaan elektronik seperti Hitachi, Seiko, Tian Ma dan lain - lain menyikap hal ini denga n menciptakan modul yang berfungsi sebagai pengendali layar LCD yang telah dilengkapi dengan memori, pola-pola karakter dan antarmuka kepengendali luar (I Nyoman Buda Hartawan dkk., 2018). Pada gambar 2.11 merupakan ldc 16x2 beserta i2c.

(Sumber: https://www.google.com/lcd16x2+i2c) (https://www.google.com/search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)

Gambar 2. 11 LCD 16x2 dan I2C


16

### 2.16 Relay

Relay adalah saklar yang dioperasikan dengan menggunakan listrik. Relay merupakan komponen elektromekanis yang terdiri dari 2 bagian utama yaitu elektromagnet (kumparan) dan mekanik (saklar sakelar). Relay menggunakan prinsip elektromagnetik untuk menggerakkan kontak saklar, sehingga arus listrik yang kecil dapat menghantarkan listrik bertegangan lebih tinggi. Pada Gambar 5 ditunjukkan bentuk dan simbol dari relay (Wahyudi, Saripudin, dkk., 2018).

Gambar 2. 12 Relay 5vdc 1 channel (Sumber: https://www.google.com/relay) (https://www.google.com/search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)

### 2.17 Solar Cell

Sel surya atau juga sering disebut fotovoltaik adalah device yang mampu mengkonversikan langsung cahaya matahari menjadi listrik. Solar cell dapat dianalogikan sebagai device dengan dua terminal atau sambungan, dimana saat kondisi gela p atau tidak cukup cahaya berfungsi seperti dioda, dan saat disinari dengan cahaya matahari dapat menghasilkan tegangan. Ketika disinari, umumnya satu sel surya komersial menghasilkan tegangan DC sebesar 0.5 sampai 1 volt, dan arus short-circuit dalam skala milliampere per cm²
. Besar tegangan dan arus
ini tidak cukup untuk berbagai aplikasi, sehingga umumnya sejumlah sel surya disusun secara seri membentuk modul solar cell. Satu modul solar cell biasanya terdiri dari 28-36 solar cell, dan total menghasilkan tegangan DC sebesar 12V dalam kondisi penyinaran standar. Modul solar cell tersebut bisa digabungkan secara paralel atau seri untuk memperbesar total tegangan dan arus outputnya sesuai dengan daya yang dibutuhkan untuk aplikasi tertentu.


17

(Sumber: https://www.google.com/solar+panel) (https://www.google.com/search?q=solar+panel&tbm=isch&biw=1600&bih=795)

Sel surya konventional bekerja menggunakan prinsip p-njuction, yaitu junction antara semikonduktor tipe-p dan tipe-n. Semikonduktor ini terdiri dari ikatan-ikatan atom yang terdapat elektron sebagai penyusun dasar. Semikonduktor tipe-n mempunyai kelebihan elektron (muatan negatif), sedangkan semikonduktor tipe-p mempunyai kelebihan hole (muatan positif) dalam struktur atomnya. Peran dari P-N junction ini adalah untuk membentuk medan listrik sehingga elektron (hole) bisa diekstrak oleh material kontak untuk menghasilkan listrik. Cara kerja sel surya diilustrasikan pada gambar 2.14 (Nurhadi dkk., 2017).

(Sumber: https://www.google.com/cara+kerja_selsurya) (https://www.google.com/search?tbm=isch&biw=1600&bih=795)

Gambar 2. 13 Solar panel

Gambar 2. 14 Cara kerja sel surya prinsip p-n junction

18

### 2.18 Batrai aki kering

Batrai VRLA (Valve-Regulated Lead-acid) atau yang sering disebut sebagai aki kering adalah salah satu tipe baterai yang sering dipakai pada kendaraan listrik maupun gas, sepeda listrik, tempat penyimpanan daya untuk pembangkit energi baru terbarukan, maupun perangkat lainnya seperti robot. Aki kering sring dipilih karena hanya membutuhkan pemeliharaan yang minim dibandingkan aki basah Pada gambar 2.15 menunjukkan bentuk aki kering 12V/5Ah berkode series ATZ5S-BS(Qintara dkk., 2020)

(Sumber: https://www.google.com/aki (https://www.google.com/search?q=aki+kering+12v/5ah&tbm=isch&biw=1600&bih=795)

### 2.19 Arduino Uno

Arduino adalah merupakan sebuah board minimum system mikrokontroler yang bersifat open source. Didalam rangkaian board arduino terdapat mikrokontroler AVR seri ATMega 328 yang merupakan produk dari Atmel. Arduino adalah sebuah board mikrokontroler yang berbasis ATmega328. Arduino memiliki 14 pin input/output yang mana 6 pin dapat digunakan sebagai output PWM, 6 analog input, crystal osilator 16 MHz, koneksi USB, jack power, kepala ICSP, dan tombol reset. Arduino mampu men-support mikrokontroler; dapat dikoneksikan dengan komputer menggunakan kabel USB Rangkaian ini berfungsi sebagai pusat kendali dari seluruh sistem yang ada, microcontroller arduino uno menggunakan bahasa pemrograman C dengan menggunakan software Arduino, pada gambar 2.16 merupakan arduino uno beserta kabel usb dan tabel 2.1 merupakan fungsi masing-masing port pada arduino uno (I Nyoman Buda Hartawan dkk., 2018).

Gambar 2. 15 Baterai aki kering

19

(Sumber: https://www.arduino.cc/en/Guide/ArduinoUno)

Tabel 2. 1 Deskripsi pin arduinouno

Kategori | Nama Pin | Detail
Power | Vin, 3.3V, 5V, GND | Vin: Voltase Input ke Arduino ketika menggunakan sumber daya external. 5V: Untuk memberikan power microcontroller dan komponen yang berada pada board Arduino. 3.3V: 3.3V supply generated by on-board voltage regulator. Maximum current draw is 50mA. GND: ground pins.
Reset | Reset | Resets microcontroller.
Analog Pins | A0 – A5 | Analog input di range of 0-5V

Gambar 2. 16 Arduino uno

20

Input/Output Pins | Digital Pins 0 - 13 | Input atau Output pin
Serial | 0(Rx), 1(Tx) | Menerima dan transmit TTL serial data.
External Interrupts | 2, 3 | Untuk mentrigger interrupt.
PWM | 3, 5, 6, 9, 11 | Menyediakan 8-bit PWM output.
SPI | 10 (SS), 11 (MOSI), 12 (MISO) and 13 (SCK) | Komunikasi SPI
Inbuilt LED | 13 | Menyalakan inbuild LED.
TWI | A4 (SDA), A5 (SCA) | Untuk Komunikasi TWI
AREF | AREF | Untuk menyediakan tegangan referensi

### 2.20 Teknik analisis data

Untuk mengetahui ketelitian pengujian alat diperlukan metode saat mengolah data yang didapat. Setelah mendapat data dari hasil pengukuran berat ikan, maka selanjutnya adalah menganalisa kadar air pada ikan. Kadar air basah merupakan kandungan air yang terkandung pada ikan dengan menggunakan persamaan dibawah ini untuk melakukan perhitungan kadar air basah (Hatta dkk., 2019).


21

Pada gambar 2.17 menunjukkan syarat mutu kadar air maksimal mencapai 40% berdasarkan standar SNI-01-2721-1992. Kadar garam berkisar 20%, dan abu tak larut dalam asam 1,5%. Setelah mendapat data dari hasil pengukuran dan pengujian berat ikan oleh sensor loadcell dan timbangan digital, maka langkah selanjutnya adalah menganalisa data tersebut untuk dilakukan proses perhitungan analisa nilai persentase (%) keakuratan, dan nilai persentase (%) kesalahan. Rumus-rumus untuk menghitung dan mencari persentase digunakan persamaan 2-5 sebagai berikut (Wahyudi, Rahman, dkk., 2018)(Achlison dan Suhartono, 2020);

Persentase akurasi = 100% - persentase selisih rata-rata | (2)

Gambar 2. 17 Syarat mutu SNI-01-2721-1992

22

Rata – rata =

S1 + S2 + S3
X

(3)
Persentase kesalahan pengukuran = S−X
S
x 100% | (4)
Persentase selisih = Selisih
Nilaiaktual
x 100% | (5)

### 2.21 Flowchart

Flowchart merupakan sebuah teknik yang digunakan untuk menjelaskan rentetan dari cara kerja sistem yang dibuat yang dibuat dalambentuk simbol-simbol tertentu. Flowchart biasanya digunakan oleh seorang programmer komputer untuk menjelaskan alur dari data yang akan disajikan yang disebut dengan Flowcharting. Flowcart adalah untaian symbolgambar(chart) yangmenujukkan aliran (flow) dariproses terhadap data. symbol-symbol flowchart dapat diklasifikasikan mejadi symbol untuk program dan symbol untuk sistem (peralatan hardware) . Berikut pada tabel 2.2 adalah simbol-simbol danfungsidariflowchartyang

1 | | Terminal | Digunakan sebagai awal atau akhir dari sebuah program
2 | | Preparation | Simbol untuk mempersiapkan penyimpanan yang akan di gunakan sebagai tempat pengolahan di dalam strorage
3 | | Garis alir atau flow line | Digunakan untuk menunjukkan arah dari programyang akan dijalankan

23

### 2.22 Black box testing

Black-Box Testing merupakan Teknik pengujian perangkat lunak yang berfokus pada spesifikasi fungsional dari perangkat lunak. Blackbox Testing bekerja dengan mengabaikan struktur kontrol sehingga

4 | Simbol input dan output | Digunakan sebagai input/output dari data yang akan atau setelah diproses
5 | Simbol proses | Digunakan sebagai tempat melakukan pemrosesan dari data yang diinputkan pada program
6 | Simbol decision | Digunakan untuk perbandingan pernyataan, atau penyeleksian datayang akan memberikan pilihan untuk langkah selanjutnya.
7 | Simbol one page connector | Digunakan sebagai penghubung flowchart yang masih berada pada satu halaman yang sama
8 | Simbol off page connector | Digunakan untuk menghubungkan flowchart dengan halaman yang berbeda

24

perhatiannya difokuskan pada informasi domain. Blackbox Testing memungkinkan pengembang software untuk membuat himpunan kondisi input yang akan melatih seluruh syarat-syarat fungsional suatu program(Jaya, 2018).

Keuntungan penggunaan metode Blackbox Tetsting adalah:
1) Penguji tidak perlu memiliki pengetahuan tentang bahasa pemrograman tertentu;
2) Pengujian dilakukan dari sudut pandang pengguna, ini membantu untuk mengungkapkan ambiguitas atau inkonsistensi dalam spesifikasi persyaratan;
3) Programmer dan tester keduanya saling bergantung satu sama lain.
Kekurangan dari metode Blackbox Testing adalah:
1) Uji kasus sulit disain tanpa spesifikasi yang jelas;
2) Kemungkinan memiliki pengulangan tes yang sudah dilakukan oleh programmer;
3) Beberapa bagian back end tidak diuji sama sekali.

25

BAB III
ANALISIS DAN PERANCANGAN

### 3.1 Tempat dan waktu penelitian

Pada penelitian inidimulai pada tanggal 27 April2020, daerah yang dipilih sebagai tempat penelitian adalah pesisir pantaijalan pantai Airport, Kuta, Kabupaten Badung.

### 3.2 Teknik pengumpulan data

Teknik pengumpulan data yang digunakan oleh peneliti pada penelitian ini adalah pengumpulan data primer dan data sekunder. Data primer terdiri dari 2 metode yaitu metode wawancara dan observasi, sedangkan data sekunder terdiri dari hasil studi kepustakaan dan hasil dokumentasi.

### 3.2.1 Data primer

Pengumpulan data primer menggunakan metode wawancara dan metode observasi. Metode wawancara yang dilakukan oleh peneliti dengan cara mewawancarai narasumber secara lisan, sedangkan metode observasi dilakukan dengan cara mengambil foto kondisi areal pengeringan ikan. Berikut merupakan uraian dari masing-masing:

1) Metodewawancara
Pada pengumpulan data primer menggunakan metode wawancara, dilakukan dengan cara mewawancarai empat narasumber secara lisan. Narasumber pertama yaitu Ibu Fatimah selaku pemilik dagangan ikan dan 3 narasumber lain yang telah lanjut usia selaku nelayandidaerahpantaiSeseh dan pantai Kedonganan. Uraian hasil dari wawancara dengan Ibu Fatimah selaku pemilik usaha penjualan ikan sekaligus pengeringan ikan dapat dilihat pada lampiran 1 draft wawancara. Kesimpulan dariwawancara yangtelahdilakukanadalah;
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

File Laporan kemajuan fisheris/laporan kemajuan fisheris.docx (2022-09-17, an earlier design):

Pengisian poin C sampai dengan poin H mengikuti template berikut dan tidak dibatasi jumlah kata atau halaman namun disarankan seringkas mungkin. Dilarang menghapus/memodifikasi template ataupun menghapus penjelasan di setiap poin.

C. HASIL PELAKSANAAN PENELITIAN: Tuliskan secara ringkas hasil pelaksanaan penelitian yang telah dicapai sesuai tahun pelaksanaan penelitian. Penyajian meliputi data, hasil analisis, dan capaian luaran (wajib dan atau tambahan). Seluruh hasil atau capaian yang dilaporkan
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

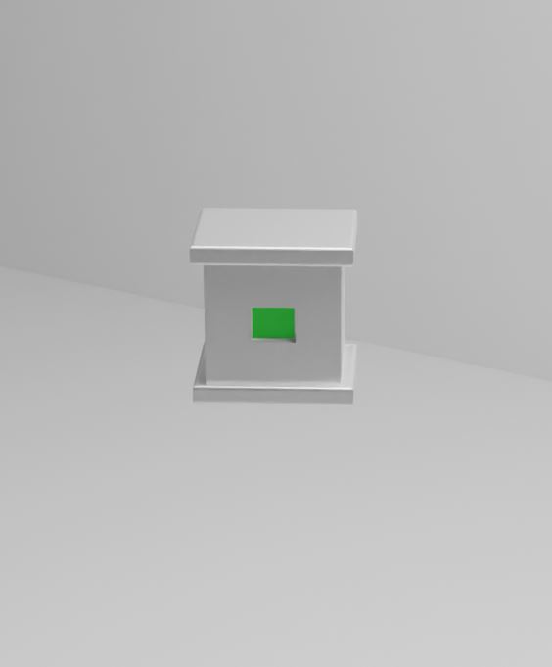
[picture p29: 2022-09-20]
Laporan kemajuan fisheris/foto/3Dbox.JPG

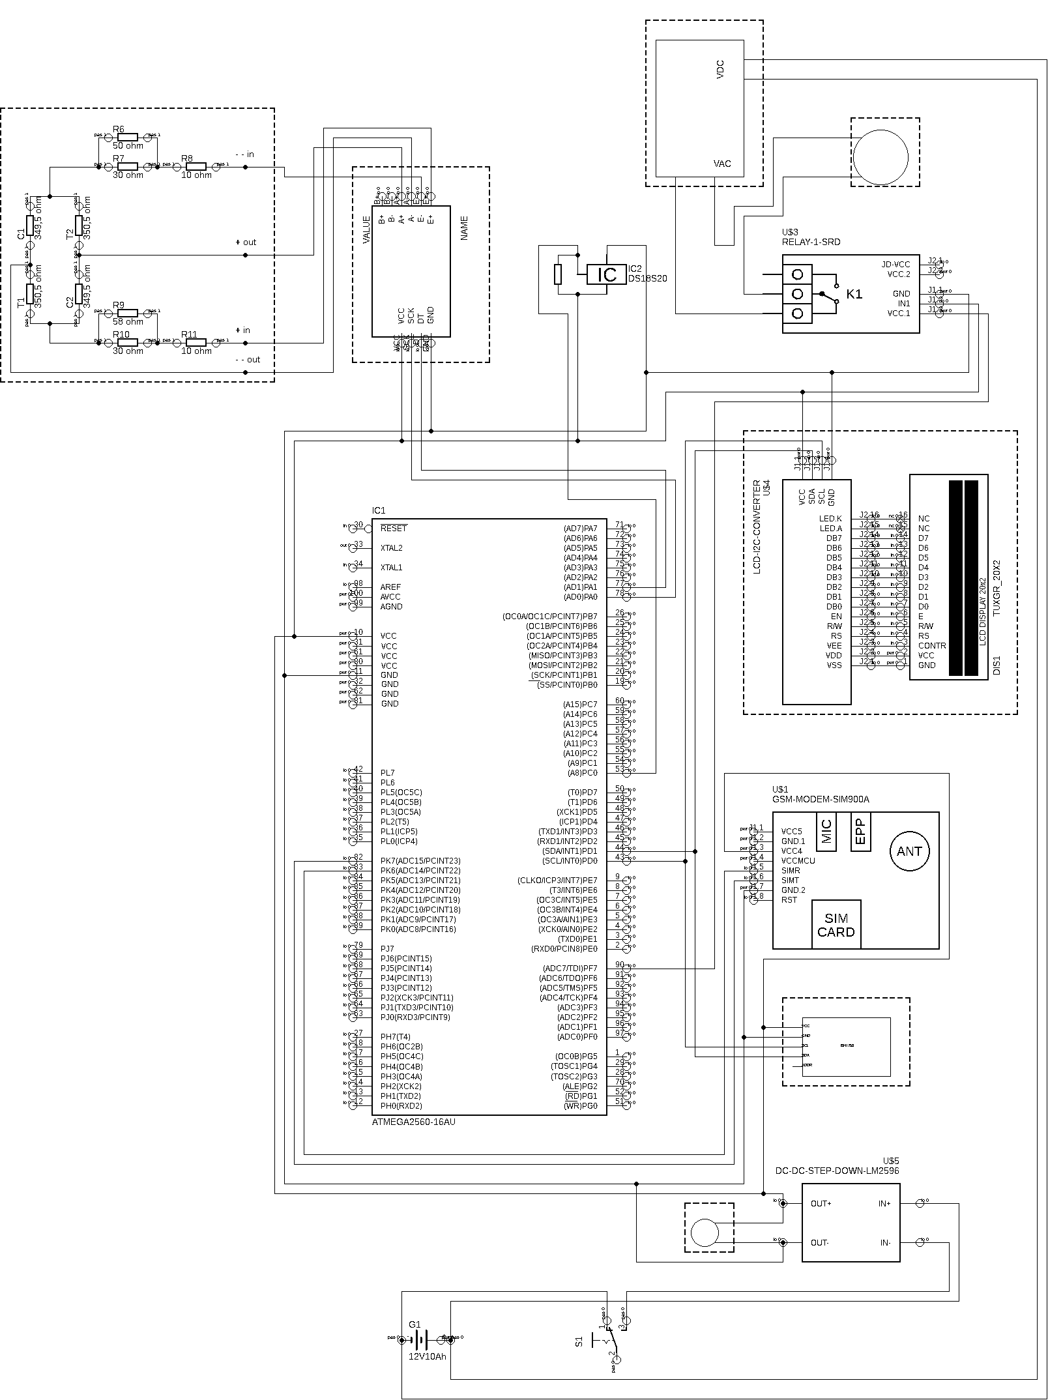
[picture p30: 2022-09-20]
Laporan kemajuan fisheris/foto/skematik.png

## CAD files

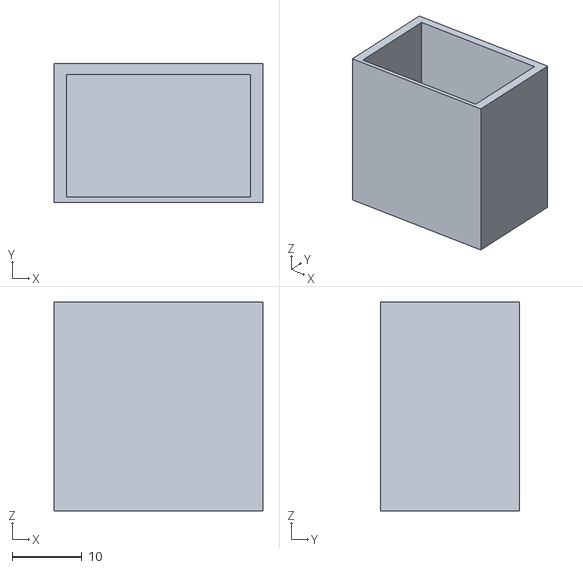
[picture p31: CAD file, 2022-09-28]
3DFIle/Glorious Snaget.stl
30.0 x 20.0 x 30.0

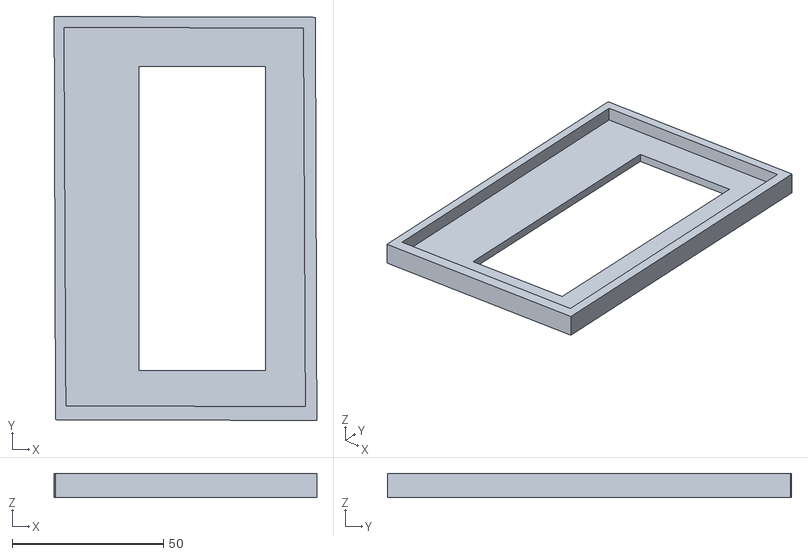
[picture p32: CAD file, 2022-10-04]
3DFIle/NewDesign/fisheriestutuplcd.stl
86.9 x 133.5 x 8.00

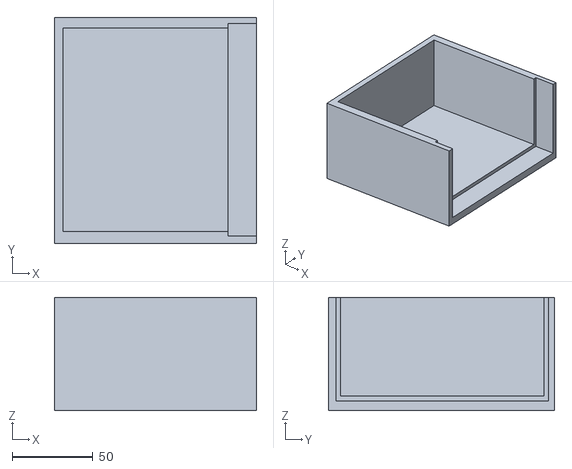
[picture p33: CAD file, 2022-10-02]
3DFIle/NewDesign/fisheriesboxkiri.stl
125.0 x 140.0 x 70.0

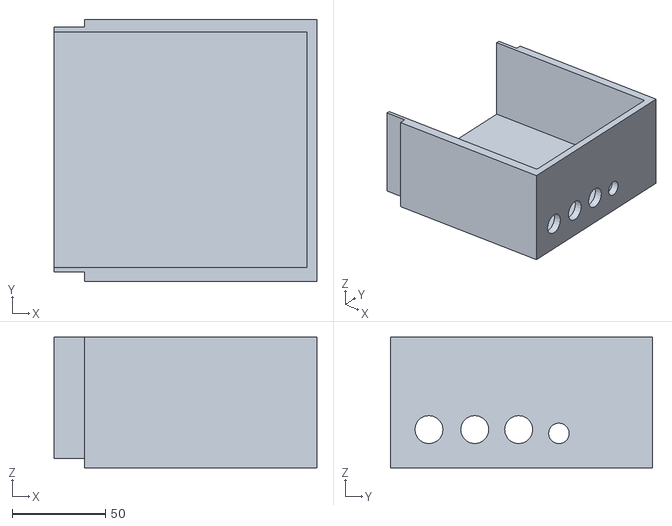
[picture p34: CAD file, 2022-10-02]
3DFIle/NewDesign/fisheriesboxkanan.stl
140.7 x 140.0 x 70.0

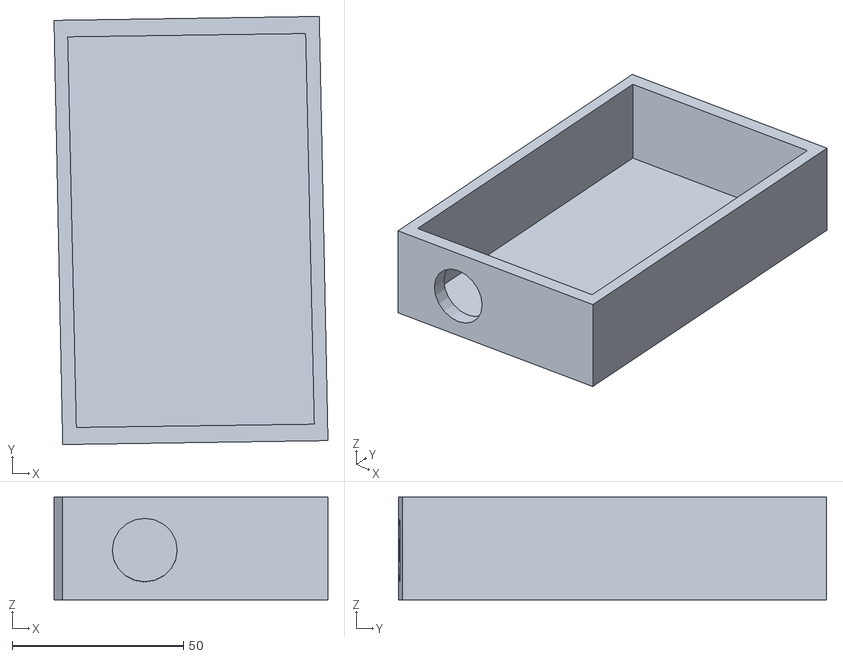
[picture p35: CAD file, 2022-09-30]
3DFIle/NewDesign/fisheriesboxlcd.stl
80.0 x 125.0 x 30.0

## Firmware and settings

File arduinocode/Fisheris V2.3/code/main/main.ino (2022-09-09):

//LIBRARIESRX
#include <LiquidCrystal_I2C.h>
#include <BH1750.h>
#include "HX711.h"
#include <OneWire.h>
#include <DallasTemperature.h>
#include <ArduinoJson.h>

#include <SoftwareSerial.h>
SoftwareSerial SIM808(10,11);//TX,RX

//INCREASE BUFFER
// #define _SS_MAX_RX_BUFF 256

// DEVICE ID AND VERSION
const String deviceId="FD001";
const String deviceVer="FHISERIS V2.3";

//PINS HX711
#define DOUT  A1
#define CLK  A0

//GSMPowerKey
#define GSMPowerKey  2

//PINS DALLASTEMP
#define ONE_WIRE_BUS A7

//PINS RELAY
#define RELAY 7

//Struct GSM
struct GSMCommandOutput{
   String inputCom;
   bool status;
   String outputCom;
};

//MODULE INITIALIZE
LiquidCrystal_I2C lcd(0x27, 20, 4);
BH1750 lightMeter;
HX711 scale(DOUT, CLK);
OneWire oneWire(ONE_WIRE_BUS);
DallasTemperature sensors(&oneWire);

float calibration_factor = 31.41; //HX711 CALIBRATION FACTOR

//URL HTTP
const String postTargetUrl="https://risetndev.com/api/logdata/store";
const String postBypassUrl="http://fishdryer.stiki-indonesia.ac.id/api/bypasstls";

//custom char
const byte tempIcon[] = {
  B00100,
  B01010,
  B01010,
  B01010,
  B01010,
  B10101,
  B10001,
  B01110
};
const byte weightIcon[] = {
  B11111,
  B01110,
  B00100,
  B01110,
  B11001,
  B10101,
  B10001,
  B01110
};
const byte signalIcon[] = {
  B00000,
  B00001,
  B00001,
  B00011,
  B00111,
  B01111,
  B11111,
  B11111
};
const byte luxIcon[] = {
  B00000,
  B00000,
  B10101,
  B01110,
  B11011,
  B01110,
  B10101,
  B00000
};
const byte relayIcon[] = {
  B00000,
  B01010,
  B01010,
  B01010,
  B11111,
  B11111,
  B01110,
  B00100
};

//Location Struck
struct location{
   float latitude;
   float longitude;
};

//Module Variable
int simSignal;
float weight,temp,lux;
boolean relayStat=0;
int relayOffSens=100;
location cordinate{
  NULL,
  NULL
};

// Sending Timer
unsigned long curretTime;
unsigned long pastSentTime;
const int sendDelay =3000;

void writeLCD(String msg,int row=0,int collum=0){
  lcd.setCursor(collum,row);//collum,row
  lcd.print(msg);
}

void writeLCDIcon(char *icon,int row=0,int collum=0){
  int id;
  if(icon=="tempIcon"){
    id=0;
    lcd.createChar(id, tempIcon);
    lcd.setCursor(collum,row);//collum,row
    lcd.write(id);

  }  
 else if(icon=="weightIcon"){
    id=1;
    lcd.createChar(id, weightIcon);
    lcd.setCursor(collum,row);//collum,row
    lcd.write(id);

 }
 else if(icon=="signalIcon"){
    id=2;
    lcd.createChar(id, signalIcon);
    lcd.setCursor(collum,row);//collum,row
    lcd.write(id);

 }
 else if(icon=="luxIcon"){
    id=3;
    lcd.createChar(id, luxIcon);
    lcd.setCursor(collum,row);//collum,row
    lcd.write(id);

 }
 else if(icon=="relayIcon"){
    id=4;
    lcd.createChar(id, relayIcon);
    lcd.setCursor(collum,row);//collum,row
    lcd.write(id);
 }
}

void clearLCD(){
  lcd.clear();
}

void clearLCD(int row,int collumStart,int collumEnd){
  for(int i=collumStart;i<=collumEnd;i++){
    lcd.setCursor(i,row);
    lcd.print(" ");
  }
}

void clearLCD(boolean row1,boolean row2,boolean row3,boolean row4){
  if(row1){
    lcd.setCursor(0,0);
    lcd.print("                    ");
  }
  if(row2){
    lcd.setCursor(0,1);
    lcd.print("                    ");
  }
  if(row3){
    lcd.setCursor(0,2);
    lcd.print("                    ");
  }
  if(row4){
    lcd.setCursor(0,3);
    lcd.print("                    ");
  }
}

void setupLoadCell(){
  clearLCD(0,1,1,1);
  Serial.println(F(""));
  Serial.println(F("-SET UP LOADCELL-"));
  writeLCD("--SETUP LOADCELL--",1,1);
  
  Serial.println("Set Default Calibration Factor : " +String(calibration_factor));
  writeLCD("Calibration Factor",2,1);
  writeLCD(String(calibration_factor),3,((20-String(calibration_factor).length())/2));
  scale.set_scale(calibration_factor);
  delay(2000);
  clearLCD(0,0,1,1);
  
  Serial.println(F("Set Tare......."));
  writeLCD("Setup Tare",2,5);
  
  Serial.println(F("In 5....."));
  writeLCD("In 5.....",3,6);
  delay(1000);
  Serial.println(F("In 4.... "));
  writeLCD("In 4.... ",3,6);
  delay(1000);
  Serial.println(F("In 3...  "));
  writeLCD("In 3...  ",3,6);
  delay(1000);
  Serial.println(F("In 2..   "));
  writeLCD("In 2..   ",3,6);
  delay(1000);
  Serial.println(F("In 1.    "));
  writeLCD("In 1.    ",3,6);
  delay(1000);
  Serial.println(F("Tare Set"));
  clearLCD(0,0,0,1);
  writeLCD("Tare Set",3,6);
  scale.tare();
  delay(1000);
  
  clearLCD(0,1,1,1);
  Serial.println(F(""));
}

void setupLCD(){
  Serial.println(F(""));
  Serial.println(F("-SET UP LCD-"));
  lcd.begin();
  lcd.backlight();
  clearLCD();
  Serial.println(F("Setup Complete"));
  Serial.println(F(""));
}

void setupLightMeter(){
  clearLCD(0,1,1,1);
  Serial.println(F(""));
  
  Serial.println(F("-SET UP  LIGHTMETER-"));
  writeLCD("-SET UP  LIGHTMETER-",1,0);
  lightMeter.begin();
  
  Serial.println("Waiting Sensor To Get Value.......");
  writeLCD("Getting Value...",2,2);
  delay(1000);
  
  while(lux==0){
    getLux();
  }
  
  Serial.println("Got Value : "+String(lux)+" lx");
  clearLCD(0,0,1,1);
  writeLCD("Got Value",2,6);
  clearLCD(0,0,0,1);
  writeLCD(String(lux)+" lx",3,((20-(String(lux)+" lx").length())/2));
  delay(1000);
  
  clearLCD(0,1,1,1);
  Serial.println(F(""));
}

void setupTemperatureSensor(){
  clearLCD(0,1,1,1);
  Serial.println(F(""));
  
  Serial.println(F("-SET UP TEMPERATURE-"));
  writeLCD("-SET UP TEMPERATURE-",1,0);
  sensors.begin();//setup temp sensor
  
  Serial.println("Waiting Sensor To Get Value.......");
  writeLCD("Getting Value...",2,2);
  delay(2000);
  
  while(temp==0){
    getTemperature();
  }
  
  Serial.println("Got Value : "+String(temp)+" C");
  clearLCD(0,0,1,1);
  writeLCD("Got Value",2,6);
  clearLCD(0,0,0,1);
  writeLCD(String(temp)+" C",3,((20-(String(temp)+" C").length())/2));
  delay(1000);
  
  clearLCD(0,1,1,1);
  Serial.println(F(""));
}

void setupRelay(){
  clearLCD(0,1,1,1);
  Serial.println(F(""));
  
  Serial.println(F("-SET UP RELAY-"));
  writeLCD("-SET UP RELAY-",1,3);
  pinMode(RELAY,OUTPUT);
  
  Serial.println("Look At the Light Bulb.......");
  writeLCD("Check Light Bulb",2,2);
  delay(2000);
  
  for (int i = 1; i <= 4; i++)
  {
    clearLCD(0,0,0,1);
    if (i % 2){
      relayStat=true;
      digitalWrite(RELAY,relayStat);
      Serial.println("relay status : " +String((relayStat)?"ON":"OFF"));
      writeLCD("Light : " +String((relayStat)?"ON":"OFF"),3,((20-("Light : " +String((relayStat)?"ON":"OFF")).length())/2));
    }
    else{
      relayStat=false;
      digitalWrite(RELAY,relayStat);
      Serial.println("relay status : " +String((relayStat)?"ON":"OFF"));
      writeLCD("Light : " +String((relayStat)?"ON":"OFF"),3,((20-("Light : " +String((relayStat)?"ON":"OFF")).length())/2));
    }
    delay(1000);
    
  }
  digitalWrite(RELAY,false);
  clearLCD(0,1,1,1);
  Serial.println(F(""));
}

float getTemperature(){
  sensors.requestTemperatures();
  temp=sensors.getTempCByIndex(0);
  return temp;
}

float getLux(){
  lux=lightMeter.readLightLevel();
  return lux;
}

float getWeight(){
  weight=scale.get_units(), 4;
  if (weight<0){
    weight=0.0;
  }
  return weight;
}

boolean getAndUpdateRelayStat(){
  relayStat=(getLux()<relayOffSens)?true:false;
  digitalWrite(RELAY,relayStat);
  return relayStat;
}

String serilizeJson(String deviceId=deviceId,float weight=weight,float temp=temp,float lux=lux,boolean relayStat=relayStat,location cordinate=cordinate){
  StaticJsonDocument<200> doc;

  doc["url"] = postTargetUrl;
  JsonObject dump_data = doc["dump"].createNestedObject("data");
  dump_data["device"] = deviceId;
  dump_data["weight"] = weight;
  dump_data["temp"] = temp;
  dump_data["lux"] = lux;
  dump_data["relay"] = relayStat;
  
  JsonObject dump_data_location = dump_data.createNestedObject("location");
  if(cordinate.latitude!=NULL || cordinate.longitude!=NULL){
    dump_data_location["latitude"] = cordinate.latitude;
    dump_data_location["longitude"] = cordinate.longitude;
  }
  else{
    dump_data_location["latitude"] = (char*)0;
    dump_data_location["longitude"] = (char*)0;
  }

  String serilize;
  serializeJson(doc, serilize);
  return serilize;
}

void GSMpowerOn()
{
  digitalWrite(GSMPowerKey,LOW);
  delay(1000);
  digitalWrite(GSMPowerKey,HIGH);
  delay(2000);
  digitalWrite(GSMPowerKey,LOW);
  delay(3000);
}

GSMCommandOutput GSMCommand(String commmand,boolean printStr=true,int timeoutWaiting=500,int charLastReceivedTimeout=500){
  if (printStr!=false)
  {
      Serial.println(F(""));
      Serial.println(F("---------------------------------------------------------------------------------------------------------------------------"));
      Serial.println(F("-GSM COMMANDS-"));
  }
  while(SIM808.available()){
    SIM808.read();
  }
  GSMCommandOutput output;
  String result;
  boolean status=false;
  char GSMCharReading[500];
  memset(GSMCharReading,0,sizeof(GSMCharReading));
  int GSMCharPos=0;
  boolean responded=false;
  unsigned long currentTime=millis();
  unsigned long charLastReceived=millis();
  unsigned long startTime=millis();

  SIM808.println(commmand);
  while(true){
    while(SIM808.available()){
      responded=true;
      GSMCharReading[GSMCharPos]=SIM808.read();
      GSMCharPos++;
      charLastReceived=millis();
      if(GSMCharPos>=sizeof(GSMCharReading)){break;}
    }
    if(millis()-startTime>timeoutWaiting && responded==false){break;}
    if(GSMCharPos>=sizeof(GSMCharReading)){break;}
    if(millis()-charLastReceived>charLastReceivedTimeout){break;}
  }
  result=String(GSMCharReading);
  
  output.inputCom=commmand;
  output.outputCom=result;

  if(result.indexOf("AT+SAPBR=0,1")!=-1 && result.indexOf("OK")!=-1){
    output.status=true;
  }
  else if(result.indexOf("AT+SAPBR=2,1")!=-1 && result.indexOf("+SAPBR: 1,1,")!=-1){
    output.status=true;
  }
  else if (result.indexOf("AT+SAPBR=3,1")!=-1 && result.indexOf("OK")!=-1)
  {
     output.status=true;
  }
  else if (result.indexOf("AT+CGNSPWR=1")!=-1 && result.indexOf("OK")!=-1)
  {
     output.status=true;
  }
  else if (result.indexOf("AT+CGNSINF")!=-1 && result.indexOf("+CGNSINF: 1,1,")!=-1)
  {
     output.status=true;
  }
  else if (result.indexOf("AT+SAPBR=1,1")!=-1 && result.indexOf("OK")!=-1)
  {
     output.status=true;
  }
  else if (result.indexOf("AT+HTTPINIT")!=-1 && result.indexOf("OK")!=-1)
  {
     output.status=true;
  }
  else if (result.indexOf("AT+HTTPPARA=\"CID\",1")!=-1 && result.indexOf("OK")!=-1)
  {
     output.status=true;
  }
  else if (result.indexOf("AT+HTTPPARA=\"URL\",")!=-1 && result.indexOf("OK")!=-1)
  {
     output.status=true;
  }
  else if (result.indexOf("AT+HTTPPARA=\"CONTENT\",\"application/json\"")!=-1 && result.indexOf("OK")!=-1)
  {
     output.status=true;
  }
  else if (result.indexOf("AT+HTTPDATA=")!=-1 && result.indexOf("DOWNLOAD")!=-1)
  {
     output.status=true;
  }
  else if (result.indexOf("AT+HTTPACTION=1")!=-1 && result.indexOf("+HTTPACTION:")!=-1 && ((result.indexOf("200")!=-1 || result.indexOf("201")!=-1)))
  {
     output.status=true;
  }
  else if (result.indexOf("AT+HTTPACTION=0")!=-1 && result.indexOf("+HTTPACTION:")!=-1 && ((result.indexOf("200")!=-1 || result.indexOf("201")!=-1)))
  {
     output.status=true;
  }
  else if (result.indexOf("AT+HTTPREAD")!=-1 && result.indexOf("+HTTPREAD")!=-1)
  {
     output.status=true;
  }
   else if (result.indexOf("AT+CSQ")!=-1 && result.indexOf("+CSQ:")!=-1)
  {
     output.status=true;
  }
  else{
    if(result.indexOf("AT")==-1 && result.indexOf("OK")!=-1){
      output.status=true;
    }
    else{
      output.status=false;
    }
  }
  if (printStr!=false)
  {
      Serial.println("Input Command : " +output.inputCom);
      Serial.println("Status : " +String(output.status));
      Serial.println(F("Output Command ["));
      Serial.println(output.outputCom);
      Serial.println(F("]"));
      Serial.println(F("-GSM COMMANDS END-"));
      Serial.println(F("---------------------------------------------------------------------------------------------------------------------------"));
      Serial.println(F(""));
  }
 
  return output;
}

void setupATComToSend(){
  GSMCommand("AT+CGNSPWR=1");
  GSMCommand("AT+SAPBR=0,1",true,1000,1000);
  GSMCommand("AT+SAPBR=3,1,\"Contype\",\"GPRS\"");
  GSMCommand("AT+SAPBR=3,1,\"APN\",\"internet\"");
  GSMCommand("AT+SAPBR=1,1",true,3000,3000);
  GSMCommand("AT+HTTPINIT");
  GSMCommand("AT+HTTPPARA=\"CID\",1");
  GSMCommand("AT+HTTPPARA=\"URL\",\""+postBypassUrl+"\"",true,3000,1000);
  GSMCommand("AT+HTTPPARA=\"CONTENT\",\"application/json\"");
}

void setupGSM(){
  clearLCD(0,1,1,1);
  Serial.println(F(""));
  
  Serial.println(F("-SET UP GSM MODEM-"));
  writeLCD("-SET UP GSM MODEM-",1,1);
  SIM808.begin(9600);
  pinMode(GSMPowerKey,OUTPUT);
  
  Serial.println("Waiting Modem To Respond.......");
  writeLCD("Wait Modem Respond",2,1);
  

  while(true){
    GSMpowerOn();
    SIM808.println("AT");
    delay(300);
    String result=SIM808.readString();
    if(result.indexOf("OK")!=-1){
      break;
    }
  }
  
  Serial.println("Modem Responded");
  clearLCD(0,0,1,1);
  writeLCD("Modem Responded",2,2);
  clearLCD(0,0,0,1);
  writeLCD("AT=OK",3,7);
  delay(1000);

  Serial.println("Connecting To Internet");
  clearLCD(0,0,1,1);
  writeLCD("Connecting Internet",2,1);
  clearLCD(0,0,0,1);
  writeLCD("Waiting To Connect",3,1);

  setupATComToSend();
  while(true){
    GSMCommandOutput checkConnection=GSMCommand("AT+SAPBR=2,1");
    if (checkConnection.status){
      break;
    }
    else{
      setupATComToSend();
    }
  }
  
  Serial.println("Connected");
  clearLCD(0,0,0,1);
  writeLCD("Connected",3,5);
  delay(1000);

  clearLCD(0,1,1,1);
  Serial.println(F(""));
}

location getCordinate(){
  GSMCommandOutput dataLocation = GSMCommand("AT+CGNSINF",false);
  if(dataLocation.status){
    String fetchLocation=dataLocation.outputCom;
    int trash1=fetchLocation.indexOf("+CGNSINF: 1,1,")+13;
    int trash2=fetchLocation.indexOf(",",trash1+1);
    int latPos=fetchLocation.indexOf(",",trash2+1);
    int longPos=fetchLocation.indexOf(",",latPos+1);
    cordinate.latitude=fetchLocation.substring(trash2+1,latPos).toFloat();
    cordinate.longitude=fetchLocation.substring(latPos+1,longPos).toFloat();
    // Serial.println(fetchLocation);
    // Serial.println(fetchLocation.substring(latPos+1,longPos));
  }
  else{
    cordinate.latitude=NULL;
    cordinate.longitude=NULL;
  }
  return cordinate;
}

void postReq(String content){
  GSMCommandOutput checkConnection=GSMCommand("AT+SAPBR=2,1");
  if (checkConnection.status==false){
    setupATComToSend();
  }
  GSMCommand("AT+HTTPDATA=" + String(content.length()) + ",10000");
  GSMCommand(content);
  GSMCommandOutput checkDataSent = GSMCommand("AT+HTTPACTION=1",true,8000,7000);
  clearLCD(0,0,0,1);
  if(checkDataSent.status!=0){
    writeLCD("-Data Sent-",3,5);
  }else{
    writeLCD("-Failed to Send-",3,2);
  }
  GSMCommand("AT+HTTPREAD",true,3000,1000);
}

int getSimSignal(){
  GSMCommandOutput dataResult=GSMCommand("AT+CSQ",false);
  if(dataResult.status==0){return 0;}
  
  String signal=dataResult.outputCom;
  // signal.trim();
  // Serial.println("1:"+signal);
  // Serial.println("signal:"+(signal.substring(signal.indexOf('+CSQ:')+2, signal.indexOf(','))));
  int safeVar=(signal.substring(signal.indexOf('+CSQ:')+2, signal.indexOf(','))).toInt();
  if (!safeVar) {
    return 0;
  }
  simSignal=safeVar;
  return simSignal;
}

void updateMainDisplay(){
  Serial.println(F(""));

  Serial.println(F("Module Status"));

  String strTmlTemp;
  String strTmlSignal;
  String strTmlWeight;
  String strTmlRelayStat;
  String strTmlLux;
  String strTmlLatLong;
  float fltTmlTemp=getTemperature();
  int fltTmlSignalStat=getSimSignal();
  float fltTmlWeight=getWeight();
  float fltTmlLux=getLux();
  boolean fltTmlRelayStat=getAndUpdateRelayStat();
  location fltLocation=getCordinate();
  
  Serial.println("temp : " + String(fltTmlTemp)+" C"); 
  if(fltTmlTemp>=100){
    strTmlTemp=":"+String(fltTmlTemp,0)+"C ";
  }
  else if(fltTmlTemp>=10)
  {
    strTmlTemp=":"+String(fltTmlTemp,1)+"C" ;
  } 
  else
  {
    strTmlTemp=":"+String(fltTmlTemp,1)+" C ";
  } 

  Serial.println("relay status : " +String((fltTmlRelayStat)?"ON":"OFF"));
  if(fltTmlRelayStat){
    strTmlRelayStat=":ON ";
  }
  else
  {
    strTmlRelayStat=":OFF ";
  }
 
  Serial.println("GSM signal : " +String(fltTmlSignalStat));
  if(fltTmlSignalStat>9){
    strTmlSignal=":"+String(fltTmlSignalStat);
  }
  else
  {
    strTmlSignal=":0"+String(fltTmlSignalStat);
  } 

  Serial.println("weight : " + String(fltTmlWeight)+" Gram");
  if (fltTmlWeight>=10000)
  {
    strTmlWeight=":"+String(fltTmlWeight/1000,1)+"Kg ";
  }
  else if(fltTmlWeight>=1000){
    strTmlWeight=":"+String(fltTmlWeight/1000,2)+"Kg ";
  }
  else if (fltTmlWeight>=100)
  {
    strTmlWeight=":"+String(int(fltTmlWeight))+"g ";
  } 
  else{
    strTmlWeight=":"+String(int(fltTmlWeight))+"g ";
  }

  Serial.println("Lux : " + String(fltTmlLux)+" Lx");
  if (fltTmlLux>=100000)
  {
    strTmlLux=":"+String(fltTmlLux/1000,1)+"KLx";
  }
  else if (fltTmlLux>=10000)
  {
    strTmlLux=":"+String(fltTmlLux/1000,1)+"KLx";
  }
  else if(fltTmlLux>=1000){
    strTmlLux=":"+String(fltTmlLux/1000,1)+"KLx";
  }
  else if (fltTmlLux>=100)
  {
    strTmlLux=":"+String(int(fltTmlLux))+"Lx";
  } 
  else{
    strTmlLux=":"+String(int(fltTmlLux))+"Lx";
  }
  int middleling=(20-(strTmlWeight.length()+strTmlLux.length())-1)/2;

  // String strTmlLatLong;
  // location fltLocation=getCordinate();
  if(fltLocation.latitude==NULL || fltLocation.longitude==NULL){
    strTmlLatLong="N:NaN E:NaN";
  }
  else{
    strTmlLatLong="N:"+String(fltLocation.latitude,3)+" E:"+String(fltLocation.longitude,3);
  }

  clearLCD(1,1,8);
  writeLCDIcon("tempIcon",1,1);
  writeLCD(strTmlTemp.substring(0, 6),1,2);

  clearLCD(1,9,14);
  writeLCDIcon("relayIcon",1,9);
  writeLCD(strTmlRelayStat.substring(0, 5),1,10);

  clearLCD(1,15,19);
  writeLCDIcon("signalIcon",1,15);
  writeLCD(strTmlSignal.substring(0, 5),1,16);

  clearLCD(0,0,1,0);
  writeLCDIcon("weightIcon",2,middleling);
  writeLCD(strTmlWeight,2,1+middleling);
  writeLCDIcon("luxIcon",2,1+middleling+strTmlWeight.length());
  writeLCD(strTmlLux,2,1+1+middleling+strTmlWeight.length());

  
  clearLCD(0,0,0,1);
  writeLCD(strTmlLatLong,3,(20-strTmlLatLong.length())/2);
  Serial.println(F(""));
}

void setup()
{
  Serial.begin(9600);
  Serial.println(deviceVer+" Begin....");
  
  setupLCD();//setup lcd
  // delay(1000);
  
  writeLCD(deviceVer,0,(20-deviceVer.length()+1)/2);//row,collum
  // delay(1000);

  setupRelay();
  // delay(1000);
  
  setupLightMeter();
  // delay(1000);
  
  setupLoadCell();//setup loadcell
  // delay(1000);
  
  setupTemperatureSensor();
  // delay(1000);
  setupGSM();
  clearLCD(0,1,1,1);
  // postReq(serilizeJson());
  curretTime=millis();
  pastSentTime=millis();
}

void loop()
{
  // while(true){
    
  // }
  if(curretTime-pastSentTime>sendDelay){
    Serial.println(F(""));
    Serial.println("Sending The Message");
    
    clearLCD(0,0,0,1);
    writeLCD("Sending Data....",3,2);

    postReq(serilizeJson(deviceId,weight,temp,lux,relayStat));

    pastSentTime=millis();
    Serial.println(F(""));
  }
  curretTime=millis();
  updateMainDisplay();
  
}

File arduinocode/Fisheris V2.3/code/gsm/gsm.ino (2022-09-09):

/* www.nyebarilmu.com */
 
//testing module

#define GSMPowerKey  2
#include <SoftwareSerial.h>
SoftwareSerial SIM808(10,11);//TX,RX

#include <ArduinoJson.h>

// CHubungkan TXD untuk Arduino pin 2 
// Hubungkan RXD untuk Arduino pin 3
char c = ' ';
int sentInterval=3000;
unsigned long lastSent=millis();
const char* url="http://ptsv2.com/t/ozsqu-1662125812/post";



void powerUpGSM(){
  pinMode(GSMPowerKey,OUTPUT);
  digitalWrite(GSMPowerKey,LOW);
  delay(1000);
  digitalWrite(GSMPowerKey,HIGH);
  delay(2000);
  digitalWrite(GSMPowerKey,LOW);
  delay(3000);
}

String serilizeJson(String api_key="test",float suhu=20,float berat=900,boolean lampu=false){
  StaticJsonDocument<128> doc;

  JsonObject data = doc.createNestedObject("data");
  data["device"] = "FD001";
  data["weight"] = 50000;
  data["temp"] = 200;
  data["lux"] = 1000000;
  data["relay"] = true;
  
  JsonObject data_location = data.createNestedObject("location");
  data_location["lat"] = "09876543";
  data_location["long"] = "6789098765";
  String output;
  serializeJson(doc, output);
//  String output="{\"api_key\":\""+api_key+"\",\"suhu\":"+(suhu)+",\"berat\":"+String(berat)+",\"lampu\":"+String(lampu)+"}";
  return output;
}

void testGSM(){
  while(true){
     // memastikan pembacaan dari SIM800 dan dikirim datanya ke Arduino(Serial Monitor)
    if (SIM808.available())
    { c = SIM808.read();
      Serial.write(c);}
 
    // memastikan pembacaan dari SIM800 dan dikirim datanya ke Arduino(Serial Monitor)
    if (Serial.available())
    { c = Serial.read();
      SIM808.write(c);  
       }
  }
}

//void resetGSMCharReading(){
//  memset(GSMCharReading,0,sizeof(GSMCharReading));
//  GSMCharPos=0;
//}

String GSMCommand(String commmand,int timeoutProcess=500,int charLastReceivedTimeout=500){
  Serial.println("-----------------------");
  Serial.println("GSM Command");
  Serial.println("-----------------------");
  Serial.println("Typing Command:");
  Serial.println(commmand);
  char GSMCharReading[170];
  memset(GSMCharReading,0,sizeof(GSMCharReading));
  int GSMCharPos=0;
  unsigned long startTime=millis();
  unsigned long currentTime=millis();
  unsigned long charLastReceived=millis();
  SIM808.println(commmand);
  while(true){
    while(SIM808.available()){
      GSMCharReading[GSMCharPos]=SIM808.read();
      GSMCharPos++;
      charLastReceived=millis();
      if(GSMCharPos>=sizeof(GSMCharReading)){break;}
    }
    if(GSMCharPos>=sizeof(GSMCharReading)){break;}
    if(millis()-startTime>timeoutProcess){break;}
    if(millis()-charLastReceived>charLastReceivedTimeout){break;}
  }
  String result=String(GSMCharReading);
  Serial.println("");
  Serial.println("Result:");
  Serial.print(result);
  Serial.println("-----------------------");
  return result;
}

void postReq(String content){
//  Serial.println(content);
  GSMCommand("AT+SAPBR=0,1",3000,3000);
  GSMCommand("AT+SAPBR=3,1,\"Contype\",\"GPRS\"");
  GSMCommand("AT+SAPBR=3,1,\"APN\",\"internet\"");
  GSMCommand("AT+SAPBR=1,1",3000,3000);
  GSMCommand("AT+HTTPINIT");
  GSMCommand("AT+HTTPPARA=\"CID\",1");
  GSMCommand("AT+HTTPPARA=\"URL\",\""+String(url)+"\"",3000,2000);
  GSMCommand("AT+HTTPPARA=\"CONTENT\",\"application/json\"");
  GSMCommand("AT+HTTPDATA=" + String(content.length()) + ",10000");
  GSMCommand(content);
  GSMCommand("AT+HTTPACTION=1",7000,5000);
  GSMCommand("AT+HTTPREAD",3000,3000);
}
void getReq(){
//  String data="{\"Test\":\"HI\"}";
  GSMCommand("AT+SAPBR=0,1",3000,3000);
  GSMCommand("AT+SAPBR=3,1,\"Contype\",\"GPRS\"");
  GSMCommand("AT+SAPBR=3,1,\"APN\",\"internet\"");
  GSMCommand("AT+SAPBR=1,1",3000,3000);
  GSMCommand("AT+HTTPINIT");
  GSMCommand("AT+HTTPPARA=\"CID\",1");
  GSMCommand("AT+HTTPPARA=\"URL\",\""+String(url)+"\"");
  GSMCommand("AT+HTTPACTION=0",7000,5000);
  GSMCommand("AT+HTTPREAD",3000,3000);
}


void setup() 
{
    powerUpGSM();
    Serial.begin(9600); //Menggunakan komunikasi serial pada 9600bps
    delay(1000);
    Serial.println(F("Serial Started"));
    SIM808.begin(9600);  
    delay(1000);
    Serial.println("Serial For GSM Started");
    testGSM();
//    postReq(serilizeJson());
//    getReq();
}

void loop()
{
  
}

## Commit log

2022-08-29 add arduino folder
2022-09-01 create arduino code POST TCP
2022-09-19 laporan fixing
    [Book1.xlsx]
2022-09-20 add skematik
    [perhitungan kebutuhan solar panel.xlsx]
2022-09-28 Create Glorious Snaget.stl
    [Glorious Snaget.stl]
2022-09-29 convert to stl file
    [fisheriesboxlcd.stl, fisheriestutuplcd.stl]
2022-09-29 add box
    [fisheriesboxkanan.stl, fisheriesboxkiri.stl, fisheriestutupbox.stl]
2022-09-30 add new design
    [fisheriesboxkanan.stl, fisheriesboxkiri.stl, fisheriestutupbox.stl]
2022-10-04 add stl tutup lcd
    [fisheriesboxkanan.stl, fisheriesboxkiri.stl, fisheriesboxlcd.stl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]
